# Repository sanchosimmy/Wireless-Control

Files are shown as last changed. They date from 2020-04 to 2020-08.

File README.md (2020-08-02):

/**
@mainpage Wireless home appliances control.

@author Akshay Pampatwar (Software)
@author Sancho Simmy Louis (Hardware Circuit Design)
@author Nijil George (Android App)
@author Sabitha Susan Joseph (PCB Design)

Appliances can be controlled via switches on a control board or a bluetooth mobile app. This project is developed for Tiva C tm4c123gh6pm uC. It can control following appliances:

(i)Fan

(ii)12 V Led strip

(iii)Plug1

(iv)Plug2

Hardware profiling of fan is done in the code thus even in case of low or over voltage of AC main line, Fan speed will remain constant for a given setting.
User specific setting of fan speed,led light brightness can be enabled from bluetooth app. 

In the starting, stored i.e. last values of Fan speed and Led Intensity will be used for control. 
Remainig inputs will be taken from hardware control panel i.e. switch board.
Thus in case of electricity failure, Fan speed and Led light brighteness will be restored but on/off state of appliances will depend on states of switches. User will have to resend commands via app for wireless control.

In case of multiple users, Latest command will be considered. 
Once commands are sent over a bluetooth, o/p states will remain unnchanged even if wireless link is lost. i.e. Switch status will be ignored, But changes in switch will be incorporarted. 
E.g. Currently switch for fan is on and fan is on. Now if turn off command sent wirelessly then fan will turned off. But if switch for fan is toggled from on to off and off to on then fan will be turned on (Even if wireless link exists thus latest command is considered for final state of o/p).

	Software is divided into 3 layers.

(i)Application layer

(ii)Middle layer

(iii)Hardware Abstraction layer

For time being, for simplicity many HAL functions are defined in a Middle layer files/module. e.g. Bluetooth,fan,led,plug etc.

	Working of code: 

(i) First code initializes all the o/p pins and i/p pins. Initiallly all the o/ps are off.

(ii)Status of fan speed and led light intensity is restored from eeprom.

(iii)Depending on status of switches appliances will be turned on.

(iv)If data is sent over a bluetooth then it will be decoded and stored in a global variable.

(v)Controller continuously checks changes in states of appliances (From Switchs or Wi Command) Depending on new commands will be enforced for turning on/off or change of speed of appliances.

(vi)New commands of fan speed and intensity will be saved in an eeprom.

	Read files from Documentation\html folder for more info on software / code.
*/

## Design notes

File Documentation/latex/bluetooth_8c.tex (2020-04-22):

\hypertarget{bluetooth_8c}{}\doxysection{C\+:/\+Users/\+Akshay/workspace\+\_\+v6\+\_\+0/\+Wireless\+\_\+\+Control/bluetooth.c File Reference}
\label{bluetooth_8c}\index{C:/Users/Akshay/workspace\_v6\_0/Wireless\_Control/bluetooth.c@{C:/Users/Akshay/workspace\_v6\_0/Wireless\_Control/bluetooth.c}}

Driver for bluetooth module.  

{\ttfamily \#include \char`\"{}bluetooth.\+h\char`\"{}}\newline
{\ttfamily \#include \char`\"{}commonheader.\+h\char`\"{}}\newline
{\ttfamily \#include \char`\"{}driverlib/uart.\+h\char`\"{}}\newline
{\ttfamily \#include \char`\"{}globalvariable.\+h\char`\"{}}\newline
{\ttfamily \#include \char`\"{}pinmap.\+h\char`\"{}}\newline
Include dependency graph for bluetooth.\+c\+:\nopagebreak
\begin{figure}[H]
\begin{center}
\leavevmode
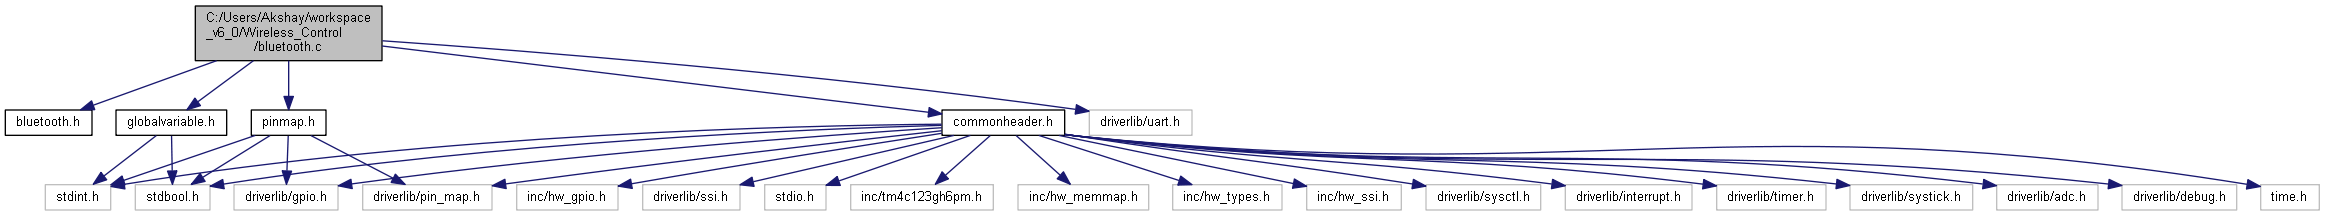
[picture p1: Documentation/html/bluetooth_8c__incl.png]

\end{center}
\end{figure}
\doxysubsection*{Functions}
\begin{DoxyCompactItemize}
\item 
void \mbox{\hyperlink{bluetooth_8c_ab92a40e570f765fd05c7c411f7a4d712}{Sys\+\_\+\+Uart\+Init}} (uint32\+\_\+t)
\item 
\mbox{\Hypertarget{bluetooth_8c_a2d4a537012aed004dd52d798fcc7498c}\label{bluetooth_8c_a2d4a537012aed004dd52d798fcc7498c}} 
void \mbox{\hyperlink{bluetooth_8c_a2d4a537012aed004dd52d798fcc7498c}{U\+A\+R\+T2\+Int\+Handler}} (void)
\begin{DoxyCompactList}\small\item\em Triggers when required depth of data rxed on Rx F\+I\+FO. \end{DoxyCompactList}\item 
\mbox{\Hypertarget{bluetooth_8c_a2ae308c73a93ebe0b32457e072f32a84}\label{bluetooth_8c_a2ae308c73a93ebe0b32457e072f32a84}} 
void \mbox{\hyperlink{bluetooth_8c_a2ae308c73a93ebe0b32457e072f32a84}{Get\+Uart\+Data}} (int32\+\_\+t Rx\+Temp)
\begin{DoxyCompactList}\small\item\em Gate fn for H\+AL to ML. I\+SR for rxed data for U\+A\+RT. \end{DoxyCompactList}\item 
\mbox{\Hypertarget{bluetooth_8c_a3931d6c801713463f51609ad20223707}\label{bluetooth_8c_a3931d6c801713463f51609ad20223707}} 
void \mbox{\hyperlink{bluetooth_8c_a3931d6c801713463f51609ad20223707}{Wip\+\_\+\+Init}} (void)
\begin{DoxyCompactList}\small\item\em Wireless input initialization for U\+A\+RT to serially communicate with bluetooth module. \end{DoxyCompactList}\end{DoxyCompactItemize}
\doxysubsection*{Variables}
\begin{DoxyCompactItemize}
\item 
\mbox{\Hypertarget{bluetooth_8c_a3948594ac93f0c5008fee3efcb07de77}\label{bluetooth_8c_a3948594ac93f0c5008fee3efcb07de77}} 
const uint32\+\_\+t {\bfseries B\+A\+U\+D\+R\+A\+TE} = 9600
\end{DoxyCompactItemize}

\doxysubsection{Detailed Description}
Driver for bluetooth module. 

\begin{DoxyAuthor}{Author}
Akshay Pampatwar 
\end{DoxyAuthor}
\begin{DoxyVersion}{Version}
0.\+0 
\end{DoxyVersion}
\begin{DoxyDate}{Date}
10th April 2020 
\end{DoxyDate}

\doxysubsection{Function Documentation}
\mbox{\Hypertarget{bluetooth_8c_ab92a40e570f765fd05c7c411f7a4d712}\label{bluetooth_8c_ab92a40e570f765fd05c7c411f7a4d712}} 
\index{bluetooth.c@{bluetooth.c}!Sys\_UartInit@{Sys\_UartInit}}
\index{Sys\_UartInit@{Sys\_UartInit}!bluetooth.c@{bluetooth.c}}
\doxysubsubsection{\texorpdfstring{Sys\_UartInit()}{Sys\_UartInit()}}
{\footnotesize\ttfamily void Sys\+\_\+\+Uart\+Init (\begin{DoxyParamCaption}\item[{uint32\+\_\+t}]{Baud\+Rate }\end{DoxyParamCaption})}

Initializez U\+A\+RT module 2 and setup I\+SR for rxed data 
\begin{DoxyParams}{Parameters}
{\em Baud\+\_\+\+Rate} & \\
\hline
\end{DoxyParams}

Definition at line 47 of file bluetooth.\+c.

Here is the caller graph for this function\+:\nopagebreak
\begin{figure}[H]
\begin{center}
\leavevmode

\end{center}
\end{figure}

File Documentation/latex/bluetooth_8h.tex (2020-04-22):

\hypertarget{bluetooth_8h}{}\doxysection{C\+:/\+Users/\+Akshay/workspace\+\_\+v6\+\_\+0/\+Wireless\+\_\+\+Control/bluetooth.h File Reference}
\label{bluetooth_8h}\index{C:/Users/Akshay/workspace\_v6\_0/Wireless\_Control/bluetooth.h@{C:/Users/Akshay/workspace\_v6\_0/Wireless\_Control/bluetooth.h}}

Function prototypes for bluetooth module.  

This graph shows which files directly or indirectly include this file\+:\nopagebreak
\begin{figure}[H]
\begin{center}
\leavevmode
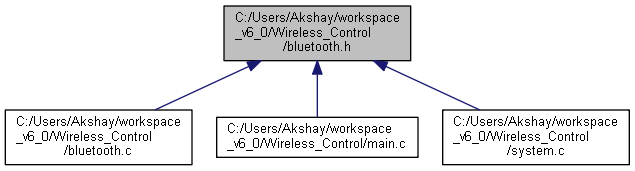
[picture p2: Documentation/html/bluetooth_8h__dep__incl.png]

\end{center}
\end{figure}
\doxysubsection*{Functions}
\begin{DoxyCompactItemize}
\item 
\mbox{\Hypertarget{bluetooth_8h_a3931d6c801713463f51609ad20223707}\label{bluetooth_8h_a3931d6c801713463f51609ad20223707}} 
void \mbox{\hyperlink{bluetooth_8h_a3931d6c801713463f51609ad20223707}{Wip\+\_\+\+Init}} (void)
\begin{DoxyCompactList}\small\item\em Wireless input initialization for U\+A\+RT to serially communicate with bluetooth module. \end{DoxyCompactList}\item 
\mbox{\Hypertarget{bluetooth_8h_ab61cf68b5b94e2ffc7ced2714f3d4968}\label{bluetooth_8h_ab61cf68b5b94e2ffc7ced2714f3d4968}} 
void \mbox{\hyperlink{bluetooth_8h_ab61cf68b5b94e2ffc7ced2714f3d4968}{Get\+Uart\+Data}} (int32\+\_\+t)
\begin{DoxyCompactList}\small\item\em Gate fn for H\+AL to ML. I\+SR for rxed data for U\+A\+RT. \end{DoxyCompactList}\end{DoxyCompactItemize}

\doxysubsection{Detailed Description}
Function prototypes for bluetooth module. 

Middle + Hardware abstraction layer. (i)Initializing serial port for communicating with bluetooth module. (ii)Updating data from user to corresponding global variable to control respective appliances. \begin{DoxyAuthor}{Author}
Akshay Pampatwar 
\end{DoxyAuthor}
\begin{DoxyVersion}{Version}
0.\+0 
\end{DoxyVersion}
\begin{DoxyDate}{Date}
10th April 2020 
\end{DoxyDate}

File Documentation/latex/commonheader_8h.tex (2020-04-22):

\hypertarget{commonheader_8h}{}\doxysection{C\+:/\+Users/\+Akshay/workspace\+\_\+v6\+\_\+0/\+Wireless\+\_\+\+Control/commonheader.h File Reference}
\label{commonheader_8h}\index{C:/Users/Akshay/workspace\_v6\_0/Wireless\_Control/commonheader.h@{C:/Users/Akshay/workspace\_v6\_0/Wireless\_Control/commonheader.h}}

Collection of header files.  

{\ttfamily \#include $<$stdio.\+h$>$}\newline
{\ttfamily \#include $<$stdint.\+h$>$}\newline
{\ttfamily \#include $<$stdbool.\+h$>$}\newline
{\ttfamily \#include \char`\"{}inc/tm4c123gh6pm.\+h\char`\"{}}\newline
{\ttfamily \#include \char`\"{}inc/hw\+\_\+memmap.\+h\char`\"{}}\newline
{\ttfamily \#include \char`\"{}inc/hw\+\_\+types.\+h\char`\"{}}\newline
{\ttfamily \#include \char`\"{}inc/hw\+\_\+ssi.\+h\char`\"{}}\newline
{\ttfamily \#include \char`\"{}driverlib/sysctl.\+h\char`\"{}}\newline
{\ttfamily \#include \char`\"{}driverlib/interrupt.\+h\char`\"{}}\newline
{\ttfamily \#include \char`\"{}driverlib/gpio.\+h\char`\"{}}\newline
{\ttfamily \#include \char`\"{}driverlib/timer.\+h\char`\"{}}\newline
{\ttfamily \#include \char`\"{}driverlib/systick.\+h\char`\"{}}\newline
{\ttfamily \#include \char`\"{}driverlib/adc.\+h\char`\"{}}\newline
{\ttfamily \#include \char`\"{}driverlib/debug.\+h\char`\"{}}\newline
{\ttfamily \#include $<$time.\+h$>$}\newline
{\ttfamily \#include $<$inc/hw\+\_\+gpio.\+h$>$}\newline
{\ttfamily \#include \char`\"{}driverlib/ssi.\+h\char`\"{}}\newline
{\ttfamily \#include \char`\"{}driverlib/pin\+\_\+map.\+h\char`\"{}}\newline
Include dependency graph for commonheader.\+h\+:\nopagebreak
\begin{figure}[H]
\begin{center}
\leavevmode

\end{center}
\end{figure}
This graph shows which files directly or indirectly include this file\+:\nopagebreak
\begin{figure}[H]
\begin{center}
\leavevmode

\end{center}
\end{figure}

\doxysubsection{Detailed Description}
Collection of header files. 

H\+AL\+: Hardware abstraction layer. Almost all header file of uC tm4c123gh6pm required to complete this project. \begin{DoxyNote}{Note}
Add it to source file of project. 
\end{DoxyNote}
\begin{DoxyAuthor}{Author}
Akshay Pampatwar 
\end{DoxyAuthor}
\begin{DoxyVersion}{Version}
0.\+0 
\end{DoxyVersion}
\begin{DoxyDate}{Date}
9th April 2020 
\end{DoxyDate}

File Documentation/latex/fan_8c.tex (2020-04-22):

\hypertarget{fan_8c}{}\doxysection{C\+:/\+Users/\+Akshay/workspace\+\_\+v6\+\_\+0/\+Wireless\+\_\+\+Control/fan.c File Reference}
\label{fan_8c}\index{C:/Users/Akshay/workspace\_v6\_0/Wireless\_Control/fan.c@{C:/Users/Akshay/workspace\_v6\_0/Wireless\_Control/fan.c}}

Driver for fan controlling.  

{\ttfamily \#include \char`\"{}fan.\+h\char`\"{}}\newline
{\ttfamily \#include \char`\"{}pinmap.\+h\char`\"{}}\newline
{\ttfamily \#include \char`\"{}commonheader.\+h\char`\"{}}\newline
{\ttfamily \#include \char`\"{}globalvariable.\+h\char`\"{}}\newline
{\ttfamily \#include \char`\"{}math.\+h\char`\"{}}\newline
Include dependency graph for fan.\+c\+:\nopagebreak
\begin{figure}[H]
\begin{center}
\leavevmode
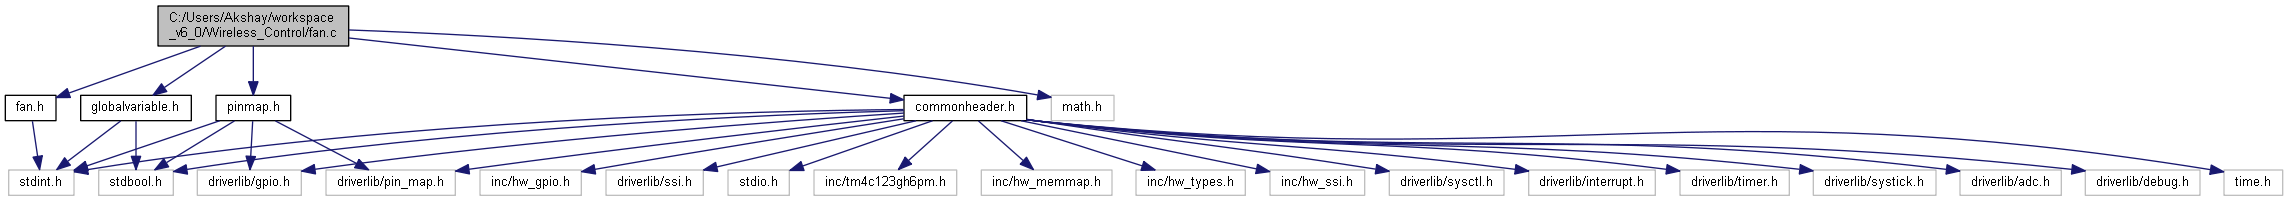
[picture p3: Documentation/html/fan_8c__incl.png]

\end{center}
\end{figure}
\doxysubsection*{Macros}
\begin{DoxyCompactItemize}
\item 
\mbox{\Hypertarget{fan_8c_a247e994e275a565320db53bed9462426}\label{fan_8c_a247e994e275a565320db53bed9462426}} 
\#define {\bfseries Scr\+Trigger\+Di}()~G\+P\+I\+O\+Int\+Disable(G\+P\+I\+O\+\_\+\+P\+O\+R\+T\+F\+\_\+\+B\+A\+SE, Z\+CD)
\item 
\mbox{\Hypertarget{fan_8c_a827d62ab62cd7dda6895929a0398709c}\label{fan_8c_a827d62ab62cd7dda6895929a0398709c}} 
\#define {\bfseries Scr\+Trigger\+En}()~G\+P\+I\+O\+Int\+Enable(G\+P\+I\+O\+\_\+\+P\+O\+R\+T\+F\+\_\+\+B\+A\+SE, Z\+CD)
\item 
\mbox{\Hypertarget{fan_8c_a7713aee3ee0d3c813de5fff0e284aa77}\label{fan_8c_a7713aee3ee0d3c813de5fff0e284aa77}} 
\#define {\bfseries S\+C\+R\+\_\+\+T\+R\+I\+G\+G\+E\+R\+\_\+\+PW}~2
\item 
\mbox{\Hypertarget{fan_8c_aa89bc308de7044aed78b7744f8bd9f2d}\label{fan_8c_aa89bc308de7044aed78b7744f8bd9f2d}} 
\#define {\bfseries Vrms\+\_\+\+Normal}~230
\end{DoxyCompactItemize}
\doxysubsection*{Functions}
\begin{DoxyCompactItemize}
\item 
\mbox{\Hypertarget{fan_8c_a2094bd7cf232d8d97c1af4a34dd2b723}\label{fan_8c_a2094bd7cf232d8d97c1af4a34dd2b723}} 
void \mbox{\hyperlink{fan_8c_a2094bd7cf232d8d97c1af4a34dd2b723}{Scr\+Pulse\+Tr}} (void)
\begin{DoxyCompactList}\small\item\em Generates 2 mS pulse to trigger fan S\+CR and Starts A\+DC sampling. \end{DoxyCompactList}\item 
\mbox{\Hypertarget{fan_8c_a048aee8573ecf21ed79e5c058fdf094d}\label{fan_8c_a048aee8573ecf21ed79e5c058fdf094d}} 
void \mbox{\hyperlink{fan_8c_a048aee8573ecf21ed79e5c058fdf094d}{Fan\+Full\+On}} (void)
\begin{DoxyCompactList}\small\item\em Turns on G\+P\+IO o/p pin of fan S\+CR for full AC vtg cycle. \end{DoxyCompactList}\item 
\mbox{\Hypertarget{fan_8c_a9aba447a5922b004e5283c120e1b5782}\label{fan_8c_a9aba447a5922b004e5283c120e1b5782}} 
void \mbox{\hyperlink{fan_8c_a9aba447a5922b004e5283c120e1b5782}{Fan\+\_\+\+Off\+\_\+\+Speed}} (void)
\begin{DoxyCompactList}\small\item\em Turns off fan if speed is 0. \end{DoxyCompactList}\item 
void \mbox{\hyperlink{fan_8c_ae2bf6e9d1d0cb94651d33913e9b038a0}{Fan\+Speed\+Ind\+Update}} (int8\+\_\+t)
\item 
\mbox{\Hypertarget{fan_8c_aa1fc5d33fce866bbc6603dbd846b2c33}\label{fan_8c_aa1fc5d33fce866bbc6603dbd846b2c33}} 
void \mbox{\hyperlink{fan_8c_aa1fc5d33fce866bbc6603dbd846b2c33}{Gpio\+Zero\+Cross\+Det\+Init}} (void)
\begin{DoxyCompactList}\small\item\em Initializes gpio pin as interrupt for rising edge trigger. For detecting zero crossing of AC vtg. \end{DoxyCompactList}\item 
void \mbox{\hyperlink{fan_8c_a97e91f37867e6a69ff463aac7c076b84}{Port\+F\+Int\+Handler}} (void)
\begin{DoxyCompactList}\small\item\em I\+SR for zero crossing.\+Update \& Starts timer1 (After that time S\+CR will be triggered) \end{DoxyCompactList}\item 
float \mbox{\hyperlink{fan_8c_a4c3218a32d123aa70edfaa91c893430a}{Vtg\+Swing\+Corr}} (float)
\item 
void \mbox{\hyperlink{fan_8c_a70802c5e162d9fbfeb1f6a27b293dc04}{Ac\+Vtg\+Rms}} (uint32\+\_\+t)
\item 
\mbox{\Hypertarget{fan_8c_a4bcca014a8288be81434b4be67f45b5a}\label{fan_8c_a4bcca014a8288be81434b4be67f45b5a}} 
void \mbox{\hyperlink{fan_8c_a4bcca014a8288be81434b4be67f45b5a}{Timer2\+B\+Init}} (void)
\begin{DoxyCompactList}\small\item\em Timer2B for pulse generation, S\+CR trigger pulse (2 mS) \end{DoxyCompactList}\item 
\mbox{\Hypertarget{fan_8c_a54477abd8e414c05f46a271e91282a14}\label{fan_8c_a54477abd8e414c05f46a271e91282a14}} 
void \mbox{\hyperlink{fan_8c_a54477abd8e414c05f46a271e91282a14}{Timer2\+B\+Int\+Handler}} (void)
\begin{DoxyCompactList}\small\item\em S\+CR pulse\+:I\+SR for Timer2B, Turns off S\+CR gpio pin. \end{DoxyCompactList}\item 
\mbox{\Hypertarget{fan_8c_a2806444250f7a6b55ea9b3ac603a52ae}\label{fan_8c_a2806444250f7a6b55ea9b3ac603a52ae}} 
void \mbox{\hyperlink{fan_8c_a2806444250f7a6b55ea9b3ac603a52ae}{Timer1\+Init}} (void)
\begin{DoxyCompactList}\small\item\em Timer1 for Scr trigger delay i.\+e. from 0 to 10 mS. \end{DoxyCompactList}\item 
\mbox{\Hypertarget{fan_8c_a65c79b40bb1ef0170ed09c5cd657f0f0}\label{fan_8c_a65c79b40bb1ef0170ed09c5cd657f0f0}} 
void \mbox{\hyperlink{fan_8c_a65c79b40bb1ef0170ed09c5cd657f0f0}{Timer1\+Int\+Handler}} (void)
\begin{DoxyCompactList}\small\item\em I\+SR for full Timer1. \end{DoxyCompactList}\item 
\mbox{\Hypertarget{fan_8c_a4aee6db188db234c1dcf4d17cc24eb03}\label{fan_8c_a4aee6db188db234c1dcf4d17cc24eb03}} 
void \mbox{\hyperlink{fan_8c_a4aee6db188db234c1dcf4d17cc24eb03}{A\+D\+C1\+\_\+\+Init}} (void)
\begin{DoxyCompactList}\small\item\em A\+DC module 1 initialize. \end{DoxyCompactList}\item 
\mbox{\Hypertarget{fan_8c_a34151cc19c669d08c8af5a052f124036}\label{fan_8c_a34151cc19c669d08c8af5a052f124036}} 
void \mbox{\hyperlink{fan_8c_a34151cc19c669d08c8af5a052f124036}{Adc1\+Int\+Handler}} (void)
\begin{DoxyCompactList}\small\item\em Takes sampled adc value and calls \mbox{\hyperlink{fan_8c_a70802c5e162d9fbfeb1f6a27b293dc04}{Ac\+Vtg\+Rms(uint32\+\_\+t)}} to save AC rms vtg. \end{DoxyCompactList}\item 
\mbox{\Hypertarget{fan_8c_abd21c776a93df2601476bddeb3300e88}\label{fan_8c_abd21c776a93df2601476bddeb3300e88}} 
void \mbox{\hyperlink{fan_8c_abd21c776a93df2601476bddeb3300e88}{Fan\+\_\+\+Init}} ()
\begin{DoxyCompactList}\small\item\em Initializes fan S\+CR driving port pin and A\+DC pin. \end{DoxyCompactList}\item 
\mbox{\Hypertarget{fan_8c_ad844825b3c02e9f2d77e61052acc3e4b}\label{fan_8c_ad844825b3c02e9f2d77e61052acc3e4b}} 
void \mbox{\hyperlink{fan_8c_ad844825b3c02e9f2d77e61052acc3e4b}{Fan\+\_\+\+On}} ()
\begin{DoxyCompactList}\small\item\em Turns on the fan, Fan speed rxed from \mbox{\hyperlink{fan_8h_a5459e7f51c969d8b256e9b5586317f92}{Fan\+\_\+\+Speed\+\_\+\+Update(int8\+\_\+t)}} function. \end{DoxyCompactList}\item 
\mbox{\Hypertarget{fan_8c_ab4c319da0d19780898b03a9b5ab658fe}\label{fan_8c_ab4c319da0d19780898b03a9b5ab658fe}} 
void \mbox{\hyperlink{fan_8c_ab4c319da0d19780898b03a9b5ab658fe}{Fan\+\_\+\+Off}} ()
\begin{DoxyCompactList}\small\item\em Turns off fan speed. \end{DoxyCompactList}\item 
void \mbox{\hyperlink{fan_8c_a45f472c9acb1834dd933b03ee530daf2}{Fan\+\_\+\+Speed\+\_\+\+Update}} (int8\+\_\+t Fan\+Speed)
\end{DoxyCompactItemize}
\doxysubsection*{Variables}
\begin{DoxyCompactItemize}
\item 
\mbox{\Hypertarget{fan_8c_a8d052979b138e8400ec8b8bb9601351b}\label{fan_8c_a8d052979b138e8400ec8b8bb9601351b}} 
float {\bfseries Scr\+Trg\+Delay} = 5.\+0
\end{DoxyCompactItemize}

\doxysubsection{Detailed Description}
Driver for fan controlling. 

\begin{DoxyAuthor}{Author}
Akshay Pampatwar 
\end{DoxyAuthor}
\begin{DoxyVersion}{Version}
0.\+0 
\end{DoxyVersion}
\begin{DoxyDate}{Date}
15th April 2020 
\end{DoxyDate}

\doxysubsection{Function Documentation}
\mbox{\Hypertarget{fan_8c_a70802c5e162d9fbfeb1f6a27b293dc04}\label{fan_8c_a70802c5e162d9fbfeb1f6a27b293dc04}} 
\index{fan.c@{fan.c}!AcVtgRms@{AcVtgRms}}
\index{AcVtgRms@{AcVtgRms}!fan.c@{fan.c}}
\doxysubsubsection{\texorpdfstring{AcVtgRms()}{AcVtgRms()}}
{\footnotesize\ttfamily void Ac\+Vtg\+Rms (\begin{DoxyParamCaption}\item[{uint32\+\_\+t}]{A\+D\+C\+Value }\end{DoxyParamCaption})}

Convert A\+DC sample into AC rms vtg and saves in Vrms variable. 
\begin{DoxyParams}{Parameters}
{\em A\+DC} & Reading\+: (uint32\+\_\+t) \\
\hline
\end{DoxyParams}

Definition at line 217 of file fan.\+c.

Here is the caller graph for this function\+:\nopagebreak
\begin{figure}[H]
\begin{center}
\leavevmode

\end{center}
\end{figure}
\mbox{\Hypertarget{fan_8c_a45f472c9acb1834dd933b03ee530daf2}\label{fan_8c_a45f472c9acb1834dd933b03ee530daf2}} 
\index{fan.c@{fan.c}!Fan\_Speed\_Update@{Fan\_Speed\_Update}}
\index{Fan\_Speed\_Update@{Fan\_Speed\_Update}!fan.c@{fan.c}}
\doxysubsubsection{\texorpdfstring{Fan\_Speed\_Update()}{Fan\_Speed\_Update()}}
{\footnotesize\ttfamily void Fan\+\_\+\+Speed\+\_\+\+Update (\begin{DoxyParamCaption}\item[{int8\+\_\+t}]{ }\end{DoxyParamCaption})}

Changes fan speed. 
\begin{DoxyParams}{Parameters}
{\em Fan\+Speed} & Fan speed from 0 to 5. lower limit should not be less than 0. \\
\hline
\end{DoxyParams}

Definition at line 126 of file fan.\+c.

Here is the call graph for this function\+:\nopagebreak
\begin{figure}[H]
\begin{center}
\leavevmode

\end{center}
\end{figure}
\mbox{\Hypertarget{fan_8c_ae2bf6e9d1d0cb94651d33913e9b038a0}\label{fan_8c_ae2bf6e9d1d0cb94651d33913e9b038a0}} 
\index{fan.c@{fan.c}!FanSpeedIndUpdate@{FanSpeedIndUpdate}}
\index{FanSpeedIndUpdate@{FanSpeedIndUpdate}!fan.c@{fan.c}}
\doxysubsubsection{\texorpdfstring{FanSpeedIndUpdate()}{FanSpeedIndUpdate()}}
{\footnotesize\ttfamily void Fan\+Speed\+Ind\+Update (\begin{DoxyParamCaption}\item[{int8\+\_\+t}]{Fan\+Speed }\end{DoxyParamCaption})}

Turns on indicator L\+ED depending on fan speed 
\begin{DoxyParams}{Parameters}
{\em Fan\+Speed} & 0 to 5 \\
\hline
\end{DoxyParams}

Definition at line 161 of file fan.\+c.

\mbox{\Hypertarget{fan_8c_a97e91f37867e6a69ff463aac7c076b84}\label{fan_8c_a97e91f37867e6a69ff463aac7c076b84}} 
\index{fan.c@{fan.c}!PortFIntHandler@{PortFIntHandler}}
\index{PortFIntHandler@{PortFIntHandler}!fan.c@{fan.c}}
\doxysubsubsection{\texorpdfstring{PortFIntHandler()}{PortFIntHandler()}}
{\footnotesize\ttfamily void Port\+F\+Int\+Handler (\begin{DoxyParamCaption}\item[{void}]{ }\end{DoxyParamCaption})}

I\+SR for zero crossing.\+Update \& Starts timer1 (After that time S\+CR will be triggered) 

Zero crossing detection I\+SR\+: Triggers Timer1 for S\+CR trigger delay. 

Definition at line 307 of file fan.\+c.

\mbox{\Hypertarget{fan_8c_a4c3218a32d123aa70edfaa91c893430a}\label{fan_8c_a4c3218a32d123aa70edfaa91c893430a}} 
\index{fan.c@{fan.c}!VtgSwingCorr@{VtgSwingCorr}}
\index{VtgSwingCorr@{VtgSwingCorr}!fan.c@{fan.c}}
\doxysubsubsection{\texorpdfstring{VtgSwingCorr()}{VtgSwingCorr()}}
{\footnotesize\ttfamily float Vtg\+Swing\+Corr (\begin{DoxyParamCaption}\item[{float}]{trigger\+Angle }\end{DoxyParamCaption})}

Correction of S\+CR trigger time depending on Line freq and AC rms voltage. 
\begin{DoxyParams}{Parameters}
{\em Trigger\+\_\+angle} & (0 to 180) \\
\hline
\end{DoxyParams}
\begin{DoxyReturn}{Returns}
Scr Trigger delay\+: (mS) Corresponding to i/p trigger angle \& AC vgt correction. 
\end{DoxyReturn}

Definition at line 152 of file fan.\+c.

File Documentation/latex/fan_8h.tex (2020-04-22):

\hypertarget{fan_8h}{}\doxysection{C\+:/\+Users/\+Akshay/workspace\+\_\+v6\+\_\+0/\+Wireless\+\_\+\+Control/fan.h File Reference}
\label{fan_8h}\index{C:/Users/Akshay/workspace\_v6\_0/Wireless\_Control/fan.h@{C:/Users/Akshay/workspace\_v6\_0/Wireless\_Control/fan.h}}

Functionn prototypes for fan controlling.  

{\ttfamily \#include $<$stdint.\+h$>$}\newline
Include dependency graph for fan.\+h\+:\nopagebreak
\begin{figure}[H]
\begin{center}
\leavevmode
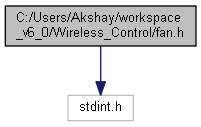
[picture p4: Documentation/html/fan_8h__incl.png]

\end{center}
\end{figure}
This graph shows which files directly or indirectly include this file\+:\nopagebreak
\begin{figure}[H]
\begin{center}
\leavevmode
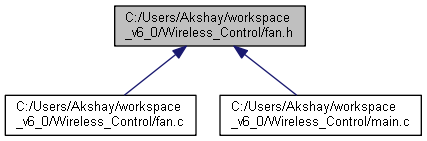
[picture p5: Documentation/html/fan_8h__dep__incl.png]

\end{center}
\end{figure}
\doxysubsection*{Functions}
\begin{DoxyCompactItemize}
\item 
\mbox{\Hypertarget{fan_8h_a3aa310cfa76c5690786c4e386ee229d9}\label{fan_8h_a3aa310cfa76c5690786c4e386ee229d9}} 
void \mbox{\hyperlink{fan_8h_a3aa310cfa76c5690786c4e386ee229d9}{Fan\+\_\+\+Init}} (void)
\begin{DoxyCompactList}\small\item\em Initializes fan S\+CR driving port pin and A\+DC pin. \end{DoxyCompactList}\item 
\mbox{\Hypertarget{fan_8h_a4867ab95fc15e966bf62fd86e3f6b51c}\label{fan_8h_a4867ab95fc15e966bf62fd86e3f6b51c}} 
void \mbox{\hyperlink{fan_8h_a4867ab95fc15e966bf62fd86e3f6b51c}{Fan\+\_\+\+On}} (void)
\begin{DoxyCompactList}\small\item\em Turns on the fan, Fan speed rxed from \mbox{\hyperlink{fan_8h_a5459e7f51c969d8b256e9b5586317f92}{Fan\+\_\+\+Speed\+\_\+\+Update(int8\+\_\+t)}} function. \end{DoxyCompactList}\item 
\mbox{\Hypertarget{fan_8h_a07cd289f0eeb148213b422ce96e71f5a}\label{fan_8h_a07cd289f0eeb148213b422ce96e71f5a}} 
void \mbox{\hyperlink{fan_8h_a07cd289f0eeb148213b422ce96e71f5a}{Fan\+\_\+\+Off}} (void)
\begin{DoxyCompactList}\small\item\em Turns off fan speed. \end{DoxyCompactList}\item 
void \mbox{\hyperlink{fan_8h_a5459e7f51c969d8b256e9b5586317f92}{Fan\+\_\+\+Speed\+\_\+\+Update}} (int8\+\_\+t)
\end{DoxyCompactItemize}

\doxysubsection{Detailed Description}
Functionn prototypes for fan controlling. 

HA + Middle layer. In case of reset of board, Saved last fan speed will be set. Requires gloabalvariable.\+h access for M\+A\+X\+F\+A\+N\+S\+P\+E\+ED value. (i)Initializes relevant port pin as an o/p, A\+DC pin and two timers. (ii)Calculates AC voltage from A\+DC reading. (iii)Depending on AC rms vtg and user provided speed, Calculates trigger delay after zero crossing of AC vtg for scr driving. (iv)In case of voltage fluctuation speed of fan will remain same.

\begin{DoxyAuthor}{Author}
Akshay Pampatwar 
\end{DoxyAuthor}
\begin{DoxyVersion}{Version}
0.\+0 
\end{DoxyVersion}
\begin{DoxyDate}{Date}
15th April 2020 
\end{DoxyDate}

\doxysubsection{Function Documentation}
\mbox{\Hypertarget{fan_8h_a5459e7f51c969d8b256e9b5586317f92}\label{fan_8h_a5459e7f51c969d8b256e9b5586317f92}} 
\index{fan.h@{fan.h}!Fan\_Speed\_Update@{Fan\_Speed\_Update}}
\index{Fan\_Speed\_Update@{Fan\_Speed\_Update}!fan.h@{fan.h}}
\doxysubsubsection{\texorpdfstring{Fan\_Speed\_Update()}{Fan\_Speed\_Update()}}
{\footnotesize\ttfamily void Fan\+\_\+\+Speed\+\_\+\+Update (\begin{DoxyParamCaption}\item[{int8\+\_\+t}]{ }\end{DoxyParamCaption})}

Changes fan speed. 
\begin{DoxyParams}{Parameters}
{\em Fan\+Speed} & Fan speed from 0 to 5. lower limit should not be less than 0. \\
\hline
\end{DoxyParams}

Definition at line 126 of file fan.\+c.

Here is the call graph for this function\+:\nopagebreak
\begin{figure}[H]
\begin{center}
\leavevmode

\end{center}
\end{figure}

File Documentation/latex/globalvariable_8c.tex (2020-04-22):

\hypertarget{globalvariable_8c}{}\doxysection{C\+:/\+Users/\+Akshay/workspace\+\_\+v6\+\_\+0/\+Wireless\+\_\+\+Control/globalvariable.c File Reference}
\label{globalvariable_8c}\index{C:/Users/Akshay/workspace\_v6\_0/Wireless\_Control/globalvariable.c@{C:/Users/Akshay/workspace\_v6\_0/Wireless\_Control/globalvariable.c}}

Gloabal variables defination and initialization.  

{\ttfamily \#include \char`\"{}globalvariable.\+h\char`\"{}}\newline
Include dependency graph for globalvariable.\+c\+:\nopagebreak
\begin{figure}[H]
\begin{center}
\leavevmode
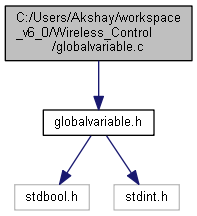
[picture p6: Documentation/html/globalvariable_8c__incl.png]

\end{center}
\end{figure}
\doxysubsection*{Variables}
\begin{DoxyCompactItemize}
\item 
\mbox{\Hypertarget{globalvariable_8c_a3672e90e5b0a8d5192c296892b24db0b}\label{globalvariable_8c_a3672e90e5b0a8d5192c296892b24db0b}} 
const int {\bfseries M\+A\+X\+\_\+\+F\+A\+N\+\_\+\+S\+P\+E\+ED} =5
\item 
\mbox{\Hypertarget{globalvariable_8c_a683a26800849e22e37dc3307f0bb2308}\label{globalvariable_8c_a683a26800849e22e37dc3307f0bb2308}} 
const int {\bfseries M\+I\+N\+\_\+\+F\+A\+N\+\_\+\+S\+P\+E\+ED} = 0
\item 
\mbox{\Hypertarget{globalvariable_8c_a4c3de1db1d0118753119c60e55481b19}\label{globalvariable_8c_a4c3de1db1d0118753119c60e55481b19}} 
const int {\bfseries M\+A\+X\+\_\+\+L\+E\+D\+\_\+\+B\+R\+I\+G\+H\+T\+N\+E\+SS} = 5
\item 
\mbox{\Hypertarget{globalvariable_8c_a611fba266ebd7798edc9829dc048fd4a}\label{globalvariable_8c_a611fba266ebd7798edc9829dc048fd4a}} 
const int {\bfseries M\+I\+N\+\_\+\+L\+E\+D\+\_\+\+B\+R\+I\+G\+H\+T\+N\+E\+SS} =0
\item 
\mbox{\Hypertarget{globalvariable_8c_adf972fab2e7892d4f81c198f2dc4285c}\label{globalvariable_8c_adf972fab2e7892d4f81c198f2dc4285c}} 
bool {\bfseries Fan\+\_\+\+Cmd} = 0
\item 
\mbox{\Hypertarget{globalvariable_8c_a955d00d52f811c7930ccc881323de958}\label{globalvariable_8c_a955d00d52f811c7930ccc881323de958}} 
int8\+\_\+t {\bfseries Fan\+\_\+\+Speed} = 0
\item 
\mbox{\Hypertarget{globalvariable_8c_af581f0be5d2aa677184ec459a8a3c7bf}\label{globalvariable_8c_af581f0be5d2aa677184ec459a8a3c7bf}} 
bool {\bfseries Led\+\_\+\+Cmd} = 0
\item 
\mbox{\Hypertarget{globalvariable_8c_aa817b5f2c7881a643c2170e419d92552}\label{globalvariable_8c_aa817b5f2c7881a643c2170e419d92552}} 
int8\+\_\+t {\bfseries Led\+\_\+\+Brightness} = 0
\item 
\mbox{\Hypertarget{globalvariable_8c_a6bec4ff681a180ff64326c6cb4187ef3}\label{globalvariable_8c_a6bec4ff681a180ff64326c6cb4187ef3}} 
bool {\bfseries Plug1\+\_\+\+Cmd} = 0
\item 
\mbox{\Hypertarget{globalvariable_8c_a31e3f498b02057d67d85c4ec56fc33f1}\label{globalvariable_8c_a31e3f498b02057d67d85c4ec56fc33f1}} 
bool {\bfseries Plug2\+\_\+\+Cmd} = 0
\item 
\mbox{\Hypertarget{globalvariable_8c_a59a42d9cfa5ec04c350a7b5c4ff5abb7}\label{globalvariable_8c_a59a42d9cfa5ec04c350a7b5c4ff5abb7}} 
bool {\bfseries Fan\+\_\+\+N\+Cmd} = 0
\item 
\mbox{\Hypertarget{globalvariable_8c_abd68eb702e45aa0ff1222aa2b889fe82}\label{globalvariable_8c_abd68eb702e45aa0ff1222aa2b889fe82}} 
bool {\bfseries Fan\+\_\+\+Nspeed} = 0
\item 
\mbox{\Hypertarget{globalvariable_8c_a5219f06eb1dc8b52a9131cf643b80156}\label{globalvariable_8c_a5219f06eb1dc8b52a9131cf643b80156}} 
bool {\bfseries Led\+\_\+\+N\+Cmd} = 0
\item 
\mbox{\Hypertarget{globalvariable_8c_a24c5e2cc3dae36d9bc7f6cfd7e150f95}\label{globalvariable_8c_a24c5e2cc3dae36d9bc7f6cfd7e150f95}} 
bool {\bfseries Led\+\_\+\+N\+Brightness} = 0
\item 
\mbox{\Hypertarget{globalvariable_8c_a624160b021593086721f383bc76e8a4c}\label{globalvariable_8c_a624160b021593086721f383bc76e8a4c}} 
bool {\bfseries Plug1\+\_\+\+N\+Cmd} = 0
\item 
\mbox{\Hypertarget{globalvariable_8c_a166340e052a5d3809e697e34c643ce07}\label{globalvariable_8c_a166340e052a5d3809e697e34c643ce07}} 
bool {\bfseries Plug2\+\_\+\+N\+Cmd} = 0
\end{DoxyCompactItemize}

\doxysubsection{Detailed Description}
Gloabal variables defination and initialization. 

\begin{DoxyAuthor}{Author}
Akshay Pampatwar 
\end{DoxyAuthor}
\begin{DoxyVersion}{Version}
0.\+0 
\end{DoxyVersion}
\begin{DoxyDate}{Date}
14th April 2020 
\end{DoxyDate}

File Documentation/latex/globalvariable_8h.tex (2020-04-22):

\hypertarget{globalvariable_8h}{}\doxysection{C\+:/\+Users/\+Akshay/workspace\+\_\+v6\+\_\+0/\+Wireless\+\_\+\+Control/globalvariable.h File Reference}
\label{globalvariable_8h}\index{C:/Users/Akshay/workspace\_v6\_0/Wireless\_Control/globalvariable.h@{C:/Users/Akshay/workspace\_v6\_0/Wireless\_Control/globalvariable.h}}

Global variables for saving status of all inputs.  

{\ttfamily \#include $<$stdbool.\+h$>$}\newline
{\ttfamily \#include $<$stdint.\+h$>$}\newline
Include dependency graph for globalvariable.\+h\+:\nopagebreak
\begin{figure}[H]
\begin{center}
\leavevmode
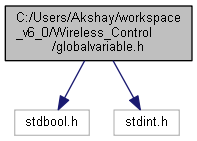
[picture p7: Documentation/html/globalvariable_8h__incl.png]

\end{center}
\end{figure}
This graph shows which files directly or indirectly include this file\+:\nopagebreak
\begin{figure}[H]
\begin{center}
\leavevmode

\end{center}
\end{figure}
\doxysubsection*{Variables}
\begin{DoxyCompactItemize}
\item 
\mbox{\Hypertarget{globalvariable_8h_a3672e90e5b0a8d5192c296892b24db0b}\label{globalvariable_8h_a3672e90e5b0a8d5192c296892b24db0b}} 
const int {\bfseries M\+A\+X\+\_\+\+F\+A\+N\+\_\+\+S\+P\+E\+ED}
\item 
\mbox{\Hypertarget{globalvariable_8h_a683a26800849e22e37dc3307f0bb2308}\label{globalvariable_8h_a683a26800849e22e37dc3307f0bb2308}} 
const int {\bfseries M\+I\+N\+\_\+\+F\+A\+N\+\_\+\+S\+P\+E\+ED}
\item 
\mbox{\Hypertarget{globalvariable_8h_a4c3de1db1d0118753119c60e55481b19}\label{globalvariable_8h_a4c3de1db1d0118753119c60e55481b19}} 
const int {\bfseries M\+A\+X\+\_\+\+L\+E\+D\+\_\+\+B\+R\+I\+G\+H\+T\+N\+E\+SS}
\item 
\mbox{\Hypertarget{globalvariable_8h_a611fba266ebd7798edc9829dc048fd4a}\label{globalvariable_8h_a611fba266ebd7798edc9829dc048fd4a}} 
const int {\bfseries M\+I\+N\+\_\+\+L\+E\+D\+\_\+\+B\+R\+I\+G\+H\+T\+N\+E\+SS}
\item 
\mbox{\Hypertarget{globalvariable_8h_adf972fab2e7892d4f81c198f2dc4285c}\label{globalvariable_8h_adf972fab2e7892d4f81c198f2dc4285c}} 
bool {\bfseries Fan\+\_\+\+Cmd}
\item 
\mbox{\Hypertarget{globalvariable_8h_a955d00d52f811c7930ccc881323de958}\label{globalvariable_8h_a955d00d52f811c7930ccc881323de958}} 
int8\+\_\+t {\bfseries Fan\+\_\+\+Speed}
\item 
\mbox{\Hypertarget{globalvariable_8h_af581f0be5d2aa677184ec459a8a3c7bf}\label{globalvariable_8h_af581f0be5d2aa677184ec459a8a3c7bf}} 
bool {\bfseries Led\+\_\+\+Cmd}
\item 
\mbox{\Hypertarget{globalvariable_8h_aa817b5f2c7881a643c2170e419d92552}\label{globalvariable_8h_aa817b5f2c7881a643c2170e419d92552}} 
int8\+\_\+t {\bfseries Led\+\_\+\+Brightness}
\item 
\mbox{\Hypertarget{globalvariable_8h_a6bec4ff681a180ff64326c6cb4187ef3}\label{globalvariable_8h_a6bec4ff681a180ff64326c6cb4187ef3}} 
bool {\bfseries Plug1\+\_\+\+Cmd}
\item 
\mbox{\Hypertarget{globalvariable_8h_a31e3f498b02057d67d85c4ec56fc33f1}\label{globalvariable_8h_a31e3f498b02057d67d85c4ec56fc33f1}} 
bool {\bfseries Plug2\+\_\+\+Cmd}
\item 
\mbox{\Hypertarget{globalvariable_8h_a59a42d9cfa5ec04c350a7b5c4ff5abb7}\label{globalvariable_8h_a59a42d9cfa5ec04c350a7b5c4ff5abb7}} 
bool {\bfseries Fan\+\_\+\+N\+Cmd}
\item 
\mbox{\Hypertarget{globalvariable_8h_abd68eb702e45aa0ff1222aa2b889fe82}\label{globalvariable_8h_abd68eb702e45aa0ff1222aa2b889fe82}} 
bool {\bfseries Fan\+\_\+\+Nspeed}
\item 
\mbox{\Hypertarget{globalvariable_8h_a5219f06eb1dc8b52a9131cf643b80156}\label{globalvariable_8h_a5219f06eb1dc8b52a9131cf643b80156}} 
bool {\bfseries Led\+\_\+\+N\+Cmd}
\item 
\mbox{\Hypertarget{globalvariable_8h_a24c5e2cc3dae36d9bc7f6cfd7e150f95}\label{globalvariable_8h_a24c5e2cc3dae36d9bc7f6cfd7e150f95}} 
bool {\bfseries Led\+\_\+\+N\+Brightness}
\item 
\mbox{\Hypertarget{globalvariable_8h_a624160b021593086721f383bc76e8a4c}\label{globalvariable_8h_a624160b021593086721f383bc76e8a4c}} 
bool {\bfseries Plug1\+\_\+\+N\+Cmd}
\item 
\mbox{\Hypertarget{globalvariable_8h_a166340e052a5d3809e697e34c643ce07}\label{globalvariable_8h_a166340e052a5d3809e697e34c643ce07}} 
bool {\bfseries Plug2\+\_\+\+N\+Cmd}
\end{DoxyCompactItemize}

\doxysubsection{Detailed Description}
Global variables for saving status of all inputs. 

Application layer and middle layer. Includes declaration of inputs of all appliances. Used for transferring data from \mbox{\hyperlink{input_8h}{input.\+h}} and \mbox{\hyperlink{bluetooth_8h}{bluetooth.\+h}} to controller. Also required for \mbox{\hyperlink{fan_8h}{fan.\+h}} and \mbox{\hyperlink{led_8h}{led.\+h}} since it uses M\+A\+X\+\_\+\+L\+E\+D\+\_\+\+B\+R\+I\+G\+H\+T\+N\+E\+SS \& M\+A\+X\+\_\+\+F\+A\+N\+\_\+\+S\+P\+E\+ED. \begin{DoxyAuthor}{Author}
Akshay Pampatwar 
\end{DoxyAuthor}
\begin{DoxyVersion}{Version}
0.\+0 
\end{DoxyVersion}
\begin{DoxyDate}{Date}
12th April 2020 
\end{DoxyDate}

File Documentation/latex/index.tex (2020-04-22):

\begin{DoxyAuthor}{Author}
Akshay Pampatwar 

Sancho Simmy Louis 

Nijil George 

Sabitha Susan Joseph
\end{DoxyAuthor}
Appliances can be controlled via switches on a control board or a bluetooth mobile app. This project is developed for Tiva C tm4c123gh6pm uC. It can control following appliances\+:

(i)Fan

(ii)12 V Led strip

(iii)Plug1

(iv)Plug2

Hardware profiling of fan is done in the code thus even in case of low or over voltage of AC main line, Fan speed will remain constant for a given setting. User specific setting of fan speed,led light brightness can be enabled from bluetooth app.

In the starting, stored i.\+e. last values of Fan speed and Led Intensity will be used for control. Remainig inputs will be taken from hardware control panel i.\+e. switch board. Thus in case of electricity failure, Fan speed and Led light brighteness will be restored but on/off state of appliances will depend on states of switches. User will have to resend commands via app for wireless control.

In case of multiple users, Latest command will be considered. Once commands are sent over a bluetooth, o/p states will remain unnchanged even if wireless link is lost. i.\+e. Switch status will be ignored, But changes in switch will be incorporarted. E.\+g. Currently switch for fan is on and fan is on. Now if turn off command sent wirelessly then fan will turned off. But if switch for fan is toggled from on to off and off to on then fan will be turned on (Even if wireless link exists thus latest command is considered for final state of o/p). \begin{DoxyVerb}Software is divided into 3 layers.
\end{DoxyVerb}

(i)Application layer

(ii)Middle layer

(iii)Hardware Abstraction layer

For time being, for simplicity many H\+AL functions are defined in a Middle layer files/module. e.\+g. Bluetooth,fan,led,plug etc. \begin{DoxyVerb}Working of code: 
\end{DoxyVerb}

(i) First code initializes all the o/p pins and i/p pins. Initiallly all the o/ps are off.

(ii)Status of fan speed and led light intensity is restored from eeprom.

(iii)Depending on status of switches appliances will be turned on.

(iv)If data is sent over a bluetooth then it will be decoded and stored in a global variable.

(v)Controller continuously checks changes in states of appliances (From Switchs or Wi Command) Depending on new commands will be enforced for turning on/off or change of speed of appliances.

(vi)New commands of fan speed and intensity will be saved in an eeprom.

$\ast$/

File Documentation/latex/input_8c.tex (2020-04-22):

\hypertarget{input_8c}{}\doxysection{C\+:/\+Users/\+Akshay/workspace\+\_\+v6\+\_\+0/\+Wireless\+\_\+\+Control/input.c File Reference}
\label{input_8c}\index{C:/Users/Akshay/workspace\_v6\_0/Wireless\_Control/input.c@{C:/Users/Akshay/workspace\_v6\_0/Wireless\_Control/input.c}}

Driver for scanning switches.  

{\ttfamily \#include \char`\"{}input.\+h\char`\"{}}\newline
{\ttfamily \#include \char`\"{}commonheader.\+h\char`\"{}}\newline
{\ttfamily \#include \char`\"{}system.\+h\char`\"{}}\newline
{\ttfamily \#include \char`\"{}globalvariable.\+h\char`\"{}}\newline
{\ttfamily \#include \char`\"{}pinmap.\+h\char`\"{}}\newline
Include dependency graph for input.\+c\+:\nopagebreak
\begin{figure}[H]
\begin{center}
\leavevmode
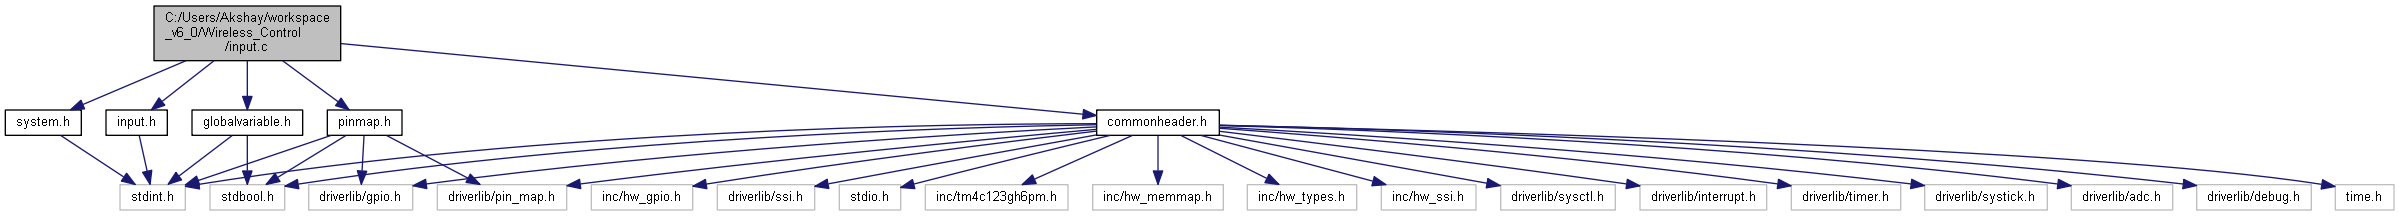
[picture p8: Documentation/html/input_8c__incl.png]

\end{center}
\end{figure}
\doxysubsection*{Macros}
\begin{DoxyCompactItemize}
\item 
\mbox{\Hypertarget{input_8c_a00aef9e8dd001a49f8717031d84b2c6c}\label{input_8c_a00aef9e8dd001a49f8717031d84b2c6c}} 
\#define {\bfseries D\+E\+B\+O\+U\+N\+C\+E\+\_\+\+T\+I\+ME}~20
\end{DoxyCompactItemize}
\doxysubsection*{Functions}
\begin{DoxyCompactItemize}
\item 
\mbox{\Hypertarget{input_8c_a5b83d6f82fe6a690e947a091d9a7f0a4}\label{input_8c_a5b83d6f82fe6a690e947a091d9a7f0a4}} 
void {\bfseries Fan\+Speed\+Update} (void)
\item 
\mbox{\Hypertarget{input_8c_a1f5fdd46fbe2c20cb8971dae6556b796}\label{input_8c_a1f5fdd46fbe2c20cb8971dae6556b796}} 
void {\bfseries Led\+Brightness\+Update} (void)
\item 
\mbox{\Hypertarget{input_8c_ab6d895e09540216fe11d738e09898794}\label{input_8c_ab6d895e09540216fe11d738e09898794}} 
void \mbox{\hyperlink{input_8c_ab6d895e09540216fe11d738e09898794}{Input\+\_\+\+Init}} (void)
\begin{DoxyCompactList}\small\item\em Middle layer fn. Initializes G\+P\+IO as an input for all the switches. \end{DoxyCompactList}\item 
void \mbox{\hyperlink{input_8c_aa824b14a8fe97b88f0ba0ed98a3e1791}{Gpip}} (uint32\+\_\+t current\+IP)
\end{DoxyCompactItemize}

\doxysubsection{Detailed Description}
Driver for scanning switches. 

\begin{DoxyAuthor}{Author}
Akshay Pampatwar 
\end{DoxyAuthor}
\begin{DoxyVersion}{Version}
0.\+0 
\end{DoxyVersion}
\begin{DoxyDate}{Date}
11th April 2020 
\end{DoxyDate}

\doxysubsection{Function Documentation}
\mbox{\Hypertarget{input_8c_aa824b14a8fe97b88f0ba0ed98a3e1791}\label{input_8c_aa824b14a8fe97b88f0ba0ed98a3e1791}} 
\index{input.c@{input.c}!Gpip@{Gpip}}
\index{Gpip@{Gpip}!input.c@{input.c}}
\doxysubsubsection{\texorpdfstring{Gpip()}{Gpip()}}
{\footnotesize\ttfamily void Gpip (\begin{DoxyParamCaption}\item[{uint32\+\_\+t}]{current\+IP }\end{DoxyParamCaption})}

I\+SR\+: Called after every debounce period (20mS). Gate called from H\+AL to Middle layer

(i)Take care of bounce back effect of switches. (ii)Updates Changed in a output to a global variable related to home appliances. 
\begin{DoxyParams}{Parameters}
{\em current\+IP} & \+: 32 bit which is an encoded status of all switches interface with Port A and Port D. 2nd last byte = Port A \& L\+S\+Byte = Port D \\
\hline
\end{DoxyParams}

Definition at line 33 of file input.\+c.

Here is the caller graph for this function\+:\nopagebreak
\begin{figure}[H]
\begin{center}
\leavevmode

\end{center}
\end{figure}

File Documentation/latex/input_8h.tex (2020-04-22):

\hypertarget{input_8h}{}\doxysection{C\+:/\+Users/\+Akshay/workspace\+\_\+v6\+\_\+0/\+Wireless\+\_\+\+Control/input.h File Reference}
\label{input_8h}\index{C:/Users/Akshay/workspace\_v6\_0/Wireless\_Control/input.h@{C:/Users/Akshay/workspace\_v6\_0/Wireless\_Control/input.h}}

Function prototype for scanning switches and updating final status of input.  

{\ttfamily \#include $<$stdint.\+h$>$}\newline
Include dependency graph for input.\+h\+:\nopagebreak
\begin{figure}[H]
\begin{center}
\leavevmode
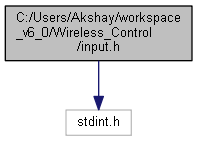
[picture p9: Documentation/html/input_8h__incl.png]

\end{center}
\end{figure}
This graph shows which files directly or indirectly include this file\+:\nopagebreak
\begin{figure}[H]
\begin{center}
\leavevmode
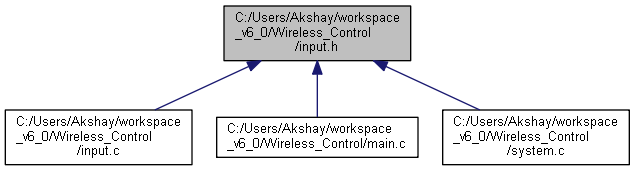
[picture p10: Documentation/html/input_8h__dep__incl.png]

\end{center}
\end{figure}
\doxysubsection*{Functions}
\begin{DoxyCompactItemize}
\item 
\mbox{\Hypertarget{input_8h_ab6d895e09540216fe11d738e09898794}\label{input_8h_ab6d895e09540216fe11d738e09898794}} 
void \mbox{\hyperlink{input_8h_ab6d895e09540216fe11d738e09898794}{Input\+\_\+\+Init}} (void)
\begin{DoxyCompactList}\small\item\em Middle layer fn. Initializes G\+P\+IO as an input for all the switches. \end{DoxyCompactList}\item 
void \mbox{\hyperlink{input_8h_aa824b14a8fe97b88f0ba0ed98a3e1791}{Gpip}} (uint32\+\_\+t current\+IP)
\end{DoxyCompactItemize}

\doxysubsection{Detailed Description}
Function prototype for scanning switches and updating final status of input. 

Middle layer. Read switches for input and updates status in global variables \begin{DoxyAuthor}{Author}
Akshay Pampatwar 
\end{DoxyAuthor}
\begin{DoxyVersion}{Version}
0.\+0 
\end{DoxyVersion}
\begin{DoxyDate}{Date}
11th April 2020 
\end{DoxyDate}

\doxysubsection{Function Documentation}
\mbox{\Hypertarget{input_8h_aa824b14a8fe97b88f0ba0ed98a3e1791}\label{input_8h_aa824b14a8fe97b88f0ba0ed98a3e1791}} 
\index{input.h@{input.h}!Gpip@{Gpip}}
\index{Gpip@{Gpip}!input.h@{input.h}}
\doxysubsubsection{\texorpdfstring{Gpip()}{Gpip()}}
{\footnotesize\ttfamily void Gpip (\begin{DoxyParamCaption}\item[{uint32\+\_\+t}]{current\+IP }\end{DoxyParamCaption})}

I\+SR\+: Called after every debounce period (20mS). Gate called from H\+AL to Middle layer

(i)Take care of bounce back effect of switches. (ii)Updates Changed in a output to a global variable related to home appliances. 
\begin{DoxyParams}{Parameters}
{\em current\+IP} & \+: 32 bit which is an encoded status of all switches interface with Port A and Port D. 2nd last byte = Port A \& L\+S\+Byte = Port D \\
\hline
\end{DoxyParams}

Definition at line 33 of file input.\+c.

Here is the caller graph for this function\+:\nopagebreak
\begin{figure}[H]
\begin{center}
\leavevmode

\end{center}
\end{figure}

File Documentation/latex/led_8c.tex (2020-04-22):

\hypertarget{led_8c}{}\doxysection{C\+:/\+Users/\+Akshay/workspace\+\_\+v6\+\_\+0/\+Wireless\+\_\+\+Control/led.c File Reference}
\label{led_8c}\index{C:/Users/Akshay/workspace\_v6\_0/Wireless\_Control/led.c@{C:/Users/Akshay/workspace\_v6\_0/Wireless\_Control/led.c}}

Driver for L\+ED strip control.  

{\ttfamily \#include \char`\"{}led.\+h\char`\"{}}\newline
{\ttfamily \#include \char`\"{}commonheader.\+h\char`\"{}}\newline
{\ttfamily \#include \char`\"{}pinmap.\+h\char`\"{}}\newline
{\ttfamily \#include \char`\"{}globalvariable.\+h\char`\"{}}\newline
Include dependency graph for led.\+c\+:\nopagebreak
\begin{figure}[H]
\begin{center}
\leavevmode
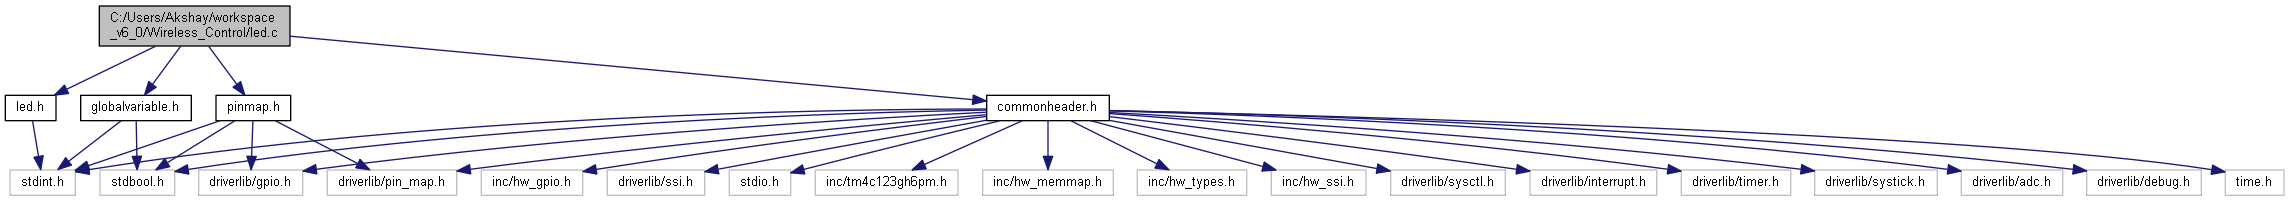
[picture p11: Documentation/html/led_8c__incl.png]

\end{center}
\end{figure}
\doxysubsection*{Functions}
\begin{DoxyCompactItemize}
\item 
\mbox{\Hypertarget{led_8c_a08d007fa711babfb56394eee2e6853dd}\label{led_8c_a08d007fa711babfb56394eee2e6853dd}} 
void \mbox{\hyperlink{led_8c_a08d007fa711babfb56394eee2e6853dd}{Timer2\+A\+P\+W\+M\+Init}} (void)
\begin{DoxyCompactList}\small\item\em Initializes Timer2A for P\+WM and configure port pin for the P\+WM o/p. \end{DoxyCompactList}\item 
\mbox{\Hypertarget{led_8c_af59abf4cefacd197620fdc094387a80d}\label{led_8c_af59abf4cefacd197620fdc094387a80d}} 
void \mbox{\hyperlink{led_8c_af59abf4cefacd197620fdc094387a80d}{Led\+\_\+\+Init}} ()
\begin{DoxyCompactList}\small\item\em Initializes o/p pin \& P\+WM for driving L\+ED. Check \mbox{\hyperlink{pinmap_8h}{pinmap.\+h}} for pin no. Uses Timer 2A. \end{DoxyCompactList}\item 
\mbox{\Hypertarget{led_8c_a95d5adeb4ba89d9b912dbab83af989cf}\label{led_8c_a95d5adeb4ba89d9b912dbab83af989cf}} 
void \mbox{\hyperlink{led_8c_a95d5adeb4ba89d9b912dbab83af989cf}{Led\+\_\+\+On}} ()
\begin{DoxyCompactList}\small\item\em Turn On L\+ED, Intensity depends on parameter passed via \mbox{\hyperlink{led_8h_af9a9d9bff04c1097512cd6a2502c8a54}{Led\+\_\+\+Intensity\+\_\+\+Update(int8\+\_\+t)}};. \end{DoxyCompactList}\item 
\mbox{\Hypertarget{led_8c_ad5564c27864e985679fd21e9dcc33f75}\label{led_8c_ad5564c27864e985679fd21e9dcc33f75}} 
void \mbox{\hyperlink{led_8c_ad5564c27864e985679fd21e9dcc33f75}{Led\+\_\+\+Off}} ()
\begin{DoxyCompactList}\small\item\em Turns Off L\+ED. \end{DoxyCompactList}\item 
\mbox{\Hypertarget{led_8c_a90c0e30307c996674bd6932d74b088b6}\label{led_8c_a90c0e30307c996674bd6932d74b088b6}} 
void \mbox{\hyperlink{led_8c_a90c0e30307c996674bd6932d74b088b6}{Led\+\_\+\+Intensity\+\_\+\+Update}} (int8\+\_\+t Led\+\_\+\+Intensity)
\begin{DoxyCompactList}\small\item\em Led Intensity\+: 0 to 5. Uses global variable for max value allowed. \end{DoxyCompactList}\end{DoxyCompactItemize}

\doxysubsection{Detailed Description}
Driver for L\+ED strip control. 

\begin{DoxyAuthor}{Author}
Akshay Pampatwar 
\end{DoxyAuthor}
\begin{DoxyVersion}{Version}
0.\+0 
\end{DoxyVersion}
\begin{DoxyDate}{Date}
Apr 17, 2020 
\end{DoxyDate}

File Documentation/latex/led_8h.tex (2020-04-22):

\hypertarget{led_8h}{}\doxysection{C\+:/\+Users/\+Akshay/workspace\+\_\+v6\+\_\+0/\+Wireless\+\_\+\+Control/led.h File Reference}
\label{led_8h}\index{C:/Users/Akshay/workspace\_v6\_0/Wireless\_Control/led.h@{C:/Users/Akshay/workspace\_v6\_0/Wireless\_Control/led.h}}

Function prototypes for L\+ED strip control.  

{\ttfamily \#include $<$stdint.\+h$>$}\newline
Include dependency graph for led.\+h\+:\nopagebreak
\begin{figure}[H]
\begin{center}
\leavevmode
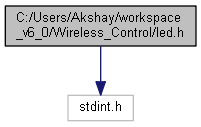
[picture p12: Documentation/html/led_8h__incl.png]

\end{center}
\end{figure}
This graph shows which files directly or indirectly include this file\+:\nopagebreak
\begin{figure}[H]
\begin{center}
\leavevmode
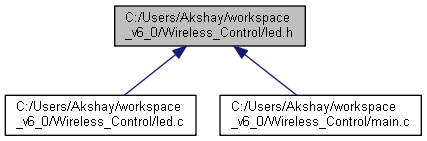
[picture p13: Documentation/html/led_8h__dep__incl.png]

\end{center}
\end{figure}
\doxysubsection*{Functions}
\begin{DoxyCompactItemize}
\item 
\mbox{\Hypertarget{led_8h_af1aee968a5ceeb7915921aa6d78aca23}\label{led_8h_af1aee968a5ceeb7915921aa6d78aca23}} 
void \mbox{\hyperlink{led_8h_af1aee968a5ceeb7915921aa6d78aca23}{Led\+\_\+\+Init}} (void)
\begin{DoxyCompactList}\small\item\em Initializes o/p pin \& P\+WM for driving L\+ED. Check \mbox{\hyperlink{pinmap_8h}{pinmap.\+h}} for pin no. Uses Timer 2A. \end{DoxyCompactList}\item 
\mbox{\Hypertarget{led_8h_a39675df62ae72fa5af35fc7ec2e8c950}\label{led_8h_a39675df62ae72fa5af35fc7ec2e8c950}} 
void \mbox{\hyperlink{led_8h_a39675df62ae72fa5af35fc7ec2e8c950}{Led\+\_\+\+On}} (void)
\begin{DoxyCompactList}\small\item\em Turn On L\+ED, Intensity depends on parameter passed via \mbox{\hyperlink{led_8h_af9a9d9bff04c1097512cd6a2502c8a54}{Led\+\_\+\+Intensity\+\_\+\+Update(int8\+\_\+t)}};. \end{DoxyCompactList}\item 
\mbox{\Hypertarget{led_8h_a274dbef77287444be852fe96969b3c55}\label{led_8h_a274dbef77287444be852fe96969b3c55}} 
void \mbox{\hyperlink{led_8h_a274dbef77287444be852fe96969b3c55}{Led\+\_\+\+Off}} (void)
\begin{DoxyCompactList}\small\item\em Turns Off L\+ED. \end{DoxyCompactList}\item 
\mbox{\Hypertarget{led_8h_af9a9d9bff04c1097512cd6a2502c8a54}\label{led_8h_af9a9d9bff04c1097512cd6a2502c8a54}} 
void \mbox{\hyperlink{led_8h_af9a9d9bff04c1097512cd6a2502c8a54}{Led\+\_\+\+Intensity\+\_\+\+Update}} (int8\+\_\+t)
\begin{DoxyCompactList}\small\item\em Led Intensity\+: 0 to 5. Uses global variable for max value allowed. \end{DoxyCompactList}\end{DoxyCompactItemize}

\doxysubsection{Detailed Description}
Function prototypes for L\+ED strip control. 

Middle layer. Initializes o/p port to command L\+ED driver. \begin{DoxyAuthor}{Author}
Akshay Pampatwar 
\end{DoxyAuthor}
\begin{DoxyVersion}{Version}
0.\+0 
\end{DoxyVersion}
\begin{DoxyDate}{Date}
Apr 17, 2020 
\end{DoxyDate}

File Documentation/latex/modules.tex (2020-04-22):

\doxysection{Modules}
Here is a list of all modules\+:\begin{DoxyCompactList}
\item \contentsline{section}{Wireless Appliances control}{\pageref{group___wi_control}}{}
\end{DoxyCompactList}

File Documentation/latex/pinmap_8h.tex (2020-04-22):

\hypertarget{pinmap_8h}{}\doxysection{C\+:/\+Users/\+Akshay/workspace\+\_\+v6\+\_\+0/\+Wireless\+\_\+\+Control/pinmap.h File Reference}
\label{pinmap_8h}\index{C:/Users/Akshay/workspace\_v6\_0/Wireless\_Control/pinmap.h@{C:/Users/Akshay/workspace\_v6\_0/Wireless\_Control/pinmap.h}}

Pin assignment of i/p \& o/p of appliances with uC.  

{\ttfamily \#include $<$stdint.\+h$>$}\newline
{\ttfamily \#include $<$stdbool.\+h$>$}\newline
{\ttfamily \#include \char`\"{}driverlib/gpio.\+h\char`\"{}}\newline
{\ttfamily \#include \char`\"{}driverlib/pin\+\_\+map.\+h\char`\"{}}\newline
Include dependency graph for pinmap.\+h\+:\nopagebreak
\begin{figure}[H]
\begin{center}
\leavevmode
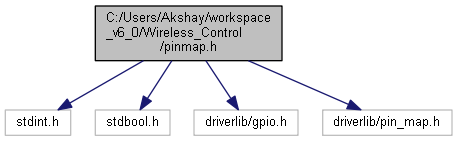
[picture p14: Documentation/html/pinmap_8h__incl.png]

\end{center}
\end{figure}
This graph shows which files directly or indirectly include this file\+:\nopagebreak
\begin{figure}[H]
\begin{center}
\leavevmode

\end{center}
\end{figure}
\doxysubsection*{Macros}
\begin{DoxyCompactItemize}
\item 
\mbox{\Hypertarget{pinmap_8h_afc65d1b0a36790c8ae7da5086d728527}\label{pinmap_8h_afc65d1b0a36790c8ae7da5086d728527}} 
\#define {\bfseries Plug1\+\_\+\+SW}~G\+P\+I\+O\+\_\+\+P\+I\+N\+\_\+0
\item 
\mbox{\Hypertarget{pinmap_8h_a3e56951e803b2091754b0cc18b9885a8}\label{pinmap_8h_a3e56951e803b2091754b0cc18b9885a8}} 
\#define {\bfseries Plug2\+\_\+\+SW}~G\+P\+I\+O\+\_\+\+P\+I\+N\+\_\+1
\item 
\mbox{\Hypertarget{pinmap_8h_a454ba58f31ecd6ad47389d354e130064}\label{pinmap_8h_a454ba58f31ecd6ad47389d354e130064}} 
\#define {\bfseries Led\+\_\+\+SW}~G\+P\+I\+O\+\_\+\+P\+I\+N\+\_\+2
\item 
\mbox{\Hypertarget{pinmap_8h_a71cc70193716ec33a70ab244665bee1f}\label{pinmap_8h_a71cc70193716ec33a70ab244665bee1f}} 
\#define {\bfseries Fan\+\_\+\+SW}~G\+P\+I\+O\+\_\+\+P\+I\+N\+\_\+3
\item 
\mbox{\Hypertarget{pinmap_8h_a2d70166aad758b72dcea20001c1a26e7}\label{pinmap_8h_a2d70166aad758b72dcea20001c1a26e7}} 
\#define {\bfseries Led\+\_\+\+Inc\+\_\+\+SW}~G\+P\+I\+O\+\_\+\+P\+I\+N\+\_\+4
\item 
\mbox{\Hypertarget{pinmap_8h_a2302ccf3a83f7dde981265daef4f13b1}\label{pinmap_8h_a2302ccf3a83f7dde981265daef4f13b1}} 
\#define {\bfseries Led\+\_\+\+Dec\+\_\+\+SW}~G\+P\+I\+O\+\_\+\+P\+I\+N\+\_\+5
\item 
\mbox{\Hypertarget{pinmap_8h_a935a3cc29014893956cd0865c8cd937a}\label{pinmap_8h_a935a3cc29014893956cd0865c8cd937a}} 
\#define {\bfseries Fan\+\_\+\+Inc\+\_\+\+SW}~G\+P\+I\+O\+\_\+\+P\+I\+N\+\_\+6
\item 
\mbox{\Hypertarget{pinmap_8h_a74a0c0af9db83c63feeb83835af6aba6}\label{pinmap_8h_a74a0c0af9db83c63feeb83835af6aba6}} 
\#define {\bfseries Fan\+\_\+\+Dec\+\_\+\+SW}~G\+P\+I\+O\+\_\+\+P\+I\+N\+\_\+7
\item 
\mbox{\Hypertarget{pinmap_8h_a57ce07898fd2d28e93ed59568ba682f9}\label{pinmap_8h_a57ce07898fd2d28e93ed59568ba682f9}} 
\#define {\bfseries Fan\+\_\+\+State}~G\+P\+I\+O\+\_\+\+P\+I\+N\+\_\+3
\item 
\mbox{\Hypertarget{pinmap_8h_add12e0168c8b9e91c84855c3869b0948}\label{pinmap_8h_add12e0168c8b9e91c84855c3869b0948}} 
\#define {\bfseries Led\+\_\+\+State}~G\+P\+I\+O\+\_\+\+P\+I\+N\+\_\+2
\item 
\mbox{\Hypertarget{pinmap_8h_a6a5cd8913182f7d82127c74deb13407d}\label{pinmap_8h_a6a5cd8913182f7d82127c74deb13407d}} 
\#define {\bfseries Fan\+\_\+1}~G\+P\+I\+O\+\_\+\+P\+I\+N\+\_\+2
\item 
\mbox{\Hypertarget{pinmap_8h_a4c6e71246541f67eef72bd519402ec46}\label{pinmap_8h_a4c6e71246541f67eef72bd519402ec46}} 
\#define {\bfseries Fan\+\_\+2}~G\+P\+I\+O\+\_\+\+P\+I\+N\+\_\+3
\item 
\mbox{\Hypertarget{pinmap_8h_a41c885b4baea527d888d66c6675d51d8}\label{pinmap_8h_a41c885b4baea527d888d66c6675d51d8}} 
\#define {\bfseries Fan\+\_\+3}~G\+P\+I\+O\+\_\+\+P\+I\+N\+\_\+0
\item 
\mbox{\Hypertarget{pinmap_8h_ab8e9b7a2ed1b2cccaf73d5f62936578e}\label{pinmap_8h_ab8e9b7a2ed1b2cccaf73d5f62936578e}} 
\#define {\bfseries Fan\+\_\+4}~G\+P\+I\+O\+\_\+\+P\+I\+N\+\_\+4
\item 
\mbox{\Hypertarget{pinmap_8h_a3c6072b9070f1fb0b794ac434ab092a8}\label{pinmap_8h_a3c6072b9070f1fb0b794ac434ab092a8}} 
\#define {\bfseries Fan\+\_\+5}~G\+P\+I\+O\+\_\+\+P\+I\+N\+\_\+0
\item 
\mbox{\Hypertarget{pinmap_8h_a832524b1941a55145906337cb19e4cb5}\label{pinmap_8h_a832524b1941a55145906337cb19e4cb5}} 
\#define {\bfseries Plug1\+\_\+\+State}~G\+P\+I\+O\+\_\+\+P\+I\+N\+\_\+2
\item 
\mbox{\Hypertarget{pinmap_8h_ab7d79da5c4739034f3e1813803f4355e}\label{pinmap_8h_ab7d79da5c4739034f3e1813803f4355e}} 
\#define {\bfseries Plug2\+\_\+\+State}~G\+P\+I\+O\+\_\+\+P\+I\+N\+\_\+3
\item 
\mbox{\Hypertarget{pinmap_8h_a5938ef724b5a81ffecf8f1499c1e8397}\label{pinmap_8h_a5938ef724b5a81ffecf8f1499c1e8397}} 
\#define {\bfseries Plug1\+\_\+\+Op}~G\+P\+I\+O\+\_\+\+P\+I\+N\+\_\+5
\item 
\mbox{\Hypertarget{pinmap_8h_a47c4193d49419fb36023036ed4d40c71}\label{pinmap_8h_a47c4193d49419fb36023036ed4d40c71}} 
\#define {\bfseries Plug2\+\_\+\+Op}~G\+P\+I\+O\+\_\+\+P\+I\+N\+\_\+6
\item 
\mbox{\Hypertarget{pinmap_8h_a8039d8bb76f824f5d0d16f0d80c5deba}\label{pinmap_8h_a8039d8bb76f824f5d0d16f0d80c5deba}} 
\#define {\bfseries Fan\+\_\+\+Scr\+\_\+\+Op}~G\+P\+I\+O\+\_\+\+P\+I\+N\+\_\+7
\item 
\mbox{\Hypertarget{pinmap_8h_a0e118bb281f2fa34a137cfb21bddf807}\label{pinmap_8h_a0e118bb281f2fa34a137cfb21bddf807}} 
\#define {\bfseries Led\+\_\+\+Op}~G\+P\+I\+O\+\_\+\+P\+F4\+\_\+\+T2\+C\+C\+P0
\item 
\mbox{\Hypertarget{pinmap_8h_a2e603822a0d3c45d48fded379ea01d2a}\label{pinmap_8h_a2e603822a0d3c45d48fded379ea01d2a}} 
\#define {\bfseries Led\+\_\+\+Op\+\_\+\+Pin}~G\+P\+I\+O\+\_\+\+P\+I\+N\+\_\+4
\item 
\mbox{\Hypertarget{pinmap_8h_a4128de22dc90ee4d9129bdcdec59ac32}\label{pinmap_8h_a4128de22dc90ee4d9129bdcdec59ac32}} 
\#define {\bfseries Z\+CD}~G\+P\+I\+O\+\_\+\+P\+I\+N\+\_\+5
\item 
\mbox{\Hypertarget{pinmap_8h_a977a75afcd68a84a4c27828336d5dbc5}\label{pinmap_8h_a977a75afcd68a84a4c27828336d5dbc5}} 
\#define {\bfseries A\+C\+\_\+\+IN}~G\+P\+I\+O\+\_\+\+P\+I\+N\+\_\+2
\item 
\mbox{\Hypertarget{pinmap_8h_a278e098e1898f109000c4bce78f3c416}\label{pinmap_8h_a278e098e1898f109000c4bce78f3c416}} 
\#define {\bfseries Bt\+\_\+\+En}~G\+P\+I\+O\+\_\+\+P\+I\+N\+\_\+5
\item 
\mbox{\Hypertarget{pinmap_8h_acff1b6b27bb18a5a6681117fce921506}\label{pinmap_8h_acff1b6b27bb18a5a6681117fce921506}} 
\#define {\bfseries Bt\+\_\+\+Tx}~G\+P\+I\+O\+\_\+\+P\+D7\+\_\+\+U2\+TX
\item 
\mbox{\Hypertarget{pinmap_8h_a09452d708e807888e4ff8906ee53edb9}\label{pinmap_8h_a09452d708e807888e4ff8906ee53edb9}} 
\#define {\bfseries Bt\+\_\+\+Rx}~G\+P\+I\+O\+\_\+\+P\+D6\+\_\+\+U2\+RX
\item 
\mbox{\Hypertarget{pinmap_8h_aed61975b933eb3fba752ae0dbfec924d}\label{pinmap_8h_aed61975b933eb3fba752ae0dbfec924d}} 
\#define {\bfseries Bt\+\_\+\+Tx\+\_\+\+Pin}~G\+P\+I\+O\+\_\+\+P\+I\+N\+\_\+7
\item 
\mbox{\Hypertarget{pinmap_8h_ad2ffd8015da8bd0647a4ac25d5ed63f3}\label{pinmap_8h_ad2ffd8015da8bd0647a4ac25d5ed63f3}} 
\#define {\bfseries Bt\+\_\+\+Rx\+\_\+\+Pin}~G\+P\+I\+O\+\_\+\+P\+I\+N\+\_\+6
\item 
\mbox{\Hypertarget{pinmap_8h_a32916a847090b087076a5bec92c78c33}\label{pinmap_8h_a32916a847090b087076a5bec92c78c33}} 
\#define {\bfseries G\+P\+I\+O\+\_\+1}~G\+P\+I\+O\+\_\+\+P\+I\+N\+\_\+0
\item 
\mbox{\Hypertarget{pinmap_8h_ae5b14b85fd16cf9cc9c37cecf533f83b}\label{pinmap_8h_ae5b14b85fd16cf9cc9c37cecf533f83b}} 
\#define {\bfseries G\+P\+I\+O\+\_\+2}~G\+P\+I\+O\+\_\+\+P\+I\+N\+\_\+1
\item 
\mbox{\Hypertarget{pinmap_8h_a90d2d5c526ce5c0a551f533eccbee71a}\label{pinmap_8h_a90d2d5c526ce5c0a551f533eccbee71a}} 
\#define {\bfseries A\+D\+C1}~G\+P\+I\+O\+\_\+\+P\+I\+N\+\_\+4
\item 
\mbox{\Hypertarget{pinmap_8h_a1803853d40a775230d2bd01a8a15ea91}\label{pinmap_8h_a1803853d40a775230d2bd01a8a15ea91}} 
\#define {\bfseries Rx}~G\+P\+I\+O\+\_\+\+P\+I\+N\+\_\+4
\item 
\mbox{\Hypertarget{pinmap_8h_abbb96fbbe5d24b8f12a1fae621ced4d3}\label{pinmap_8h_abbb96fbbe5d24b8f12a1fae621ced4d3}} 
\#define {\bfseries Tx}~G\+P\+I\+O\+\_\+\+P\+I\+N\+\_\+5
\item 
\mbox{\Hypertarget{pinmap_8h_a538e3ec60828cfabae7e3011d73d2093}\label{pinmap_8h_a538e3ec60828cfabae7e3011d73d2093}} 
\#define {\bfseries P\+WM}~G\+P\+I\+O\+\_\+\+P\+I\+N\+\_\+3
\item 
\mbox{\Hypertarget{pinmap_8h_a549c6fea143151843c75309dd1e8a0c8}\label{pinmap_8h_a549c6fea143151843c75309dd1e8a0c8}} 
\#define {\bfseries Port\+A\+\_\+\+Ip\+Mask}~( Led\+\_\+\+Inc\+\_\+\+SW $\vert$ Led\+\_\+\+Dec\+\_\+\+SW $\vert$ Fan\+\_\+\+Inc\+\_\+\+SW $\vert$ Fan\+\_\+\+Dec\+\_\+\+SW )
\item 
\mbox{\Hypertarget{pinmap_8h_a25fa364d63b3c1c6738e14eff6e427e6}\label{pinmap_8h_a25fa364d63b3c1c6738e14eff6e427e6}} 
\#define {\bfseries Port\+A\+\_\+\+Op\+Mask}~( Fan\+\_\+\+State $\vert$ Led\+\_\+\+State )
\item 
\mbox{\Hypertarget{pinmap_8h_aeb1855ded2da259d262c3ba6ba0014cf}\label{pinmap_8h_aeb1855ded2da259d262c3ba6ba0014cf}} 
\#define {\bfseries Port\+B\+\_\+\+Ip\+Mask}~( 0 )
\item 
\mbox{\Hypertarget{pinmap_8h_ab32dd7a51884ba21af9caa5ac5826023}\label{pinmap_8h_ab32dd7a51884ba21af9caa5ac5826023}} 
\#define {\bfseries Port\+B\+\_\+\+Op\+Mask}~( Fan\+\_\+1 $\vert$ Fan\+\_\+2 $\vert$ Bt\+\_\+\+En )
\item 
\mbox{\Hypertarget{pinmap_8h_ab19676f235654ab332017600cc6a3775}\label{pinmap_8h_ab19676f235654ab332017600cc6a3775}} 
\#define {\bfseries Port\+C\+\_\+\+Ip\+Mask}~( 0 )
\item 
\mbox{\Hypertarget{pinmap_8h_afb3a68ddabf48e6bc6f85a14b31325c5}\label{pinmap_8h_afb3a68ddabf48e6bc6f85a14b31325c5}} 
\#define {\bfseries Port\+C\+\_\+\+Op\+Mask}~( Fan\+\_\+4 $\vert$ Plug1\+\_\+\+Op $\vert$ Plug2\+\_\+\+Op $\vert$ Fan\+\_\+\+Scr\+\_\+\+Op)
\item 
\mbox{\Hypertarget{pinmap_8h_aaa6d797e7cbcb4965ad71cb91d838510}\label{pinmap_8h_aaa6d797e7cbcb4965ad71cb91d838510}} 
\#define {\bfseries Port\+D\+\_\+\+Ip\+Mask}~( Plug1\+\_\+\+SW $\vert$ Plug2\+\_\+\+SW $\vert$ Led\+\_\+\+SW $\vert$ Fan\+\_\+\+SW )
\item 
\mbox{\Hypertarget{pinmap_8h_aab631e3c1c2d8e93f42769bafe43b80e}\label{pinmap_8h_aab631e3c1c2d8e93f42769bafe43b80e}} 
\#define {\bfseries Port\+E\+\_\+\+Ip\+Mask}~( 0 )
\item 
\mbox{\Hypertarget{pinmap_8h_a32fbdf1228dc715809bc5a34348fdca4}\label{pinmap_8h_a32fbdf1228dc715809bc5a34348fdca4}} 
\#define {\bfseries Port\+E\+\_\+\+Op\+Mask}~( Fan\+\_\+3 )
\end{DoxyCompactItemize}

\doxysubsection{Detailed Description}
Pin assignment of i/p \& o/p of appliances with uC. 

H\+AL\+: Hardware abstraction layer. Maps pin of tm4c123gh6pm uC with corresponding functionality. \begin{DoxyNote}{Note}
U can only change P\+IN maping in the same port. i.\+e. If u want to change pin no. assignment in portA then updated pin should be assigned in a port A only. 
\end{DoxyNote}
\begin{DoxyAuthor}{Author}
\$\+Akshay Pampatwar \$ 
\end{DoxyAuthor}
\begin{DoxyVersion}{Version}
\$0.\+0 \$ 
\end{DoxyVersion}
\begin{DoxyDate}{Date}
\$10th April 2020 \$ 
\end{DoxyDate}

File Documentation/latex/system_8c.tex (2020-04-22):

\hypertarget{system_8c}{}\doxysection{C\+:/\+Users/\+Akshay/workspace\+\_\+v6\+\_\+0/\+Wireless\+\_\+\+Control/system.c File Reference}
\label{system_8c}\index{C:/Users/Akshay/workspace\_v6\_0/Wireless\_Control/system.c@{C:/Users/Akshay/workspace\_v6\_0/Wireless\_Control/system.c}}

Driver for peripherals of tm4c123gh6pm uC.  

{\ttfamily \#include \char`\"{}system.\+h\char`\"{}}\newline
{\ttfamily \#include \char`\"{}pinmap.\+h\char`\"{}}\newline
{\ttfamily \#include \char`\"{}commonheader.\+h\char`\"{}}\newline
{\ttfamily \#include \char`\"{}input.\+h\char`\"{}}\newline
{\ttfamily \#include \char`\"{}bluetooth.\+h\char`\"{}}\newline
{\ttfamily \#include \char`\"{}driverlib/uart.\+h\char`\"{}}\newline
{\ttfamily \#include \char`\"{}driverlib/eeprom.\+h\char`\"{}}\newline
Include dependency graph for system.\+c\+:\nopagebreak
\begin{figure}[H]
\begin{center}
\leavevmode
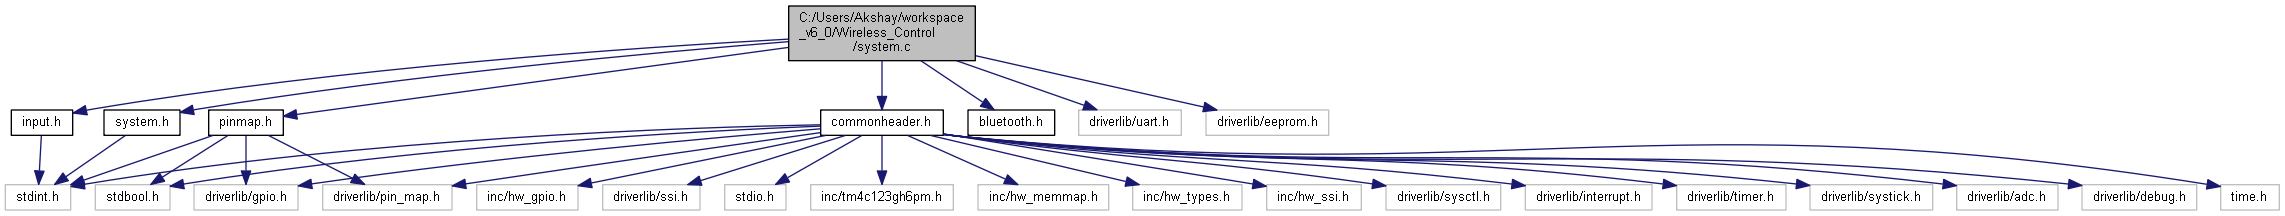
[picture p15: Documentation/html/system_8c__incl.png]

\end{center}
\end{figure}
\doxysubsection*{Functions}
\begin{DoxyCompactItemize}
\item 
void \mbox{\hyperlink{system_8c_a4de2e91e78a7dc2a2501959f85ca1bb2}{Timer0\+Init}} (uint32\+\_\+t debounce)
\item 
\mbox{\Hypertarget{system_8c_a74ceb5fbff5fd971c473d77538d3ea8c}\label{system_8c_a74ceb5fbff5fd971c473d77538d3ea8c}} 
void \mbox{\hyperlink{system_8c_a74ceb5fbff5fd971c473d77538d3ea8c}{Timer0\+Int\+Handler}} (void)
\begin{DoxyCompactList}\small\item\em I\+SR for Timer0 \+: Reads port A and D, packs it and passed on to \mbox{\hyperlink{input_8c_aa824b14a8fe97b88f0ba0ed98a3e1791}{Gpip()}} fn in \mbox{\hyperlink{input_8c}{input.\+c}}. \end{DoxyCompactList}\item 
\mbox{\Hypertarget{system_8c_adfdb874494a7e96ac1256869f1a7e9d4}\label{system_8c_adfdb874494a7e96ac1256869f1a7e9d4}} 
void \mbox{\hyperlink{system_8c_adfdb874494a7e96ac1256869f1a7e9d4}{Sys\+\_\+\+Init}} (void)
\begin{DoxyCompactList}\small\item\em Initializes system with 20M\+Hz C\+PU Clock and enable clk to all required ports. \end{DoxyCompactList}\item 
void \mbox{\hyperlink{system_8c_acf611d90e359ddd37bf100b55febf8bb}{Sys\+\_\+\+Gpip\+Init}} (uint32\+\_\+t debounce)
\item 
\mbox{\Hypertarget{system_8c_a858c121cead7d8b34a037695504b926e}\label{system_8c_a858c121cead7d8b34a037695504b926e}} 
void \mbox{\hyperlink{system_8c_a858c121cead7d8b34a037695504b926e}{Sys\+\_\+\+Eeprom\+\_\+\+Init}} ()
\begin{DoxyCompactList}\small\item\em Init eeprom. \end{DoxyCompactList}\item 
int8\+\_\+t \mbox{\hyperlink{system_8c_af287be012af33e6521b17064706323dc}{Sys\+\_\+\+Restore\+\_\+\+Byte}} (int8\+\_\+t address)
\item 
void \mbox{\hyperlink{system_8c_a95a32c6f93e18ebbb8ddd02e88014d01}{Sys\+\_\+\+Store\+\_\+\+Byte}} (int8\+\_\+t value, int8\+\_\+t address)
\end{DoxyCompactItemize}

\doxysubsection{Detailed Description}
Driver for peripherals of tm4c123gh6pm uC. 

\begin{DoxyAuthor}{Author}
Akshay Pampatwar 
\end{DoxyAuthor}
\begin{DoxyVersion}{Version}
0.\+0 
\end{DoxyVersion}
\begin{DoxyDate}{Date}
10th April 2020 
\end{DoxyDate}

\doxysubsection{Function Documentation}
\mbox{\Hypertarget{system_8c_acf611d90e359ddd37bf100b55febf8bb}\label{system_8c_acf611d90e359ddd37bf100b55febf8bb}} 
\index{system.c@{system.c}!Sys\_GpipInit@{Sys\_GpipInit}}
\index{Sys\_GpipInit@{Sys\_GpipInit}!system.c@{system.c}}
\doxysubsubsection{\texorpdfstring{Sys\_GpipInit()}{Sys\_GpipInit()}}
{\footnotesize\ttfamily void Sys\+\_\+\+Gpip\+Init (\begin{DoxyParamCaption}\item[{uint32\+\_\+t}]{debounce }\end{DoxyParamCaption})}

Initializes G\+P\+I\+Os as an input for switches and Timer 0 to take care of debounce. 
\begin{DoxyParams}{Parameters}
{\em debounce} & \+: Debounce Time setting for switches \\
\hline
\end{DoxyParams}

Definition at line 45 of file system.\+c.

Here is the caller graph for this function\+:\nopagebreak
\begin{figure}[H]
\begin{center}
\leavevmode

\end{center}
\end{figure}
\mbox{\Hypertarget{system_8c_af287be012af33e6521b17064706323dc}\label{system_8c_af287be012af33e6521b17064706323dc}} 
\index{system.c@{system.c}!Sys\_Restore\_Byte@{Sys\_Restore\_Byte}}
\index{Sys\_Restore\_Byte@{Sys\_Restore\_Byte}!system.c@{system.c}}
\doxysubsubsection{\texorpdfstring{Sys\_Restore\_Byte()}{Sys\_Restore\_Byte()}}
{\footnotesize\ttfamily int8\+\_\+t Sys\+\_\+\+Restore\+\_\+\+Byte (\begin{DoxyParamCaption}\item[{int8\+\_\+t}]{address }\end{DoxyParamCaption})}

Returns content from eeprom corresponding to address passed to it. 
\begin{DoxyParams}{Parameters}
{\em address} & 0 to n $\vert$ n belongs to Natural number \\
\hline
\end{DoxyParams}
\begin{DoxyReturn}{Returns}
Byte (int8\+\_\+t)\+: From addressed passed 
\end{DoxyReturn}

Definition at line 63 of file system.\+c.

\mbox{\Hypertarget{system_8c_a95a32c6f93e18ebbb8ddd02e88014d01}\label{system_8c_a95a32c6f93e18ebbb8ddd02e88014d01}} 
\index{system.c@{system.c}!Sys\_Store\_Byte@{Sys\_Store\_Byte}}
\index{Sys\_Store\_Byte@{Sys\_Store\_Byte}!system.c@{system.c}}
\doxysubsubsection{\texorpdfstring{Sys\_Store\_Byte()}{Sys\_Store\_Byte()}}
{\footnotesize\ttfamily void Sys\+\_\+\+Store\+\_\+\+Byte (\begin{DoxyParamCaption}\item[{int8\+\_\+t}]{value,  }\item[{int8\+\_\+t}]{address }\end{DoxyParamCaption})}

Store passed contents to an eeprom. 
\begin{DoxyParams}{Parameters}
{\em value} & 8 bit data which needs to be stored \\
\hline
{\em address} & 0 to n $\vert$ n belongs to Natural number \\
\hline
\end{DoxyParams}

Definition at line 70 of file system.\+c.

\mbox{\Hypertarget{system_8c_a4de2e91e78a7dc2a2501959f85ca1bb2}\label{system_8c_a4de2e91e78a7dc2a2501959f85ca1bb2}} 
\index{system.c@{system.c}!Timer0Init@{Timer0Init}}
\index{Timer0Init@{Timer0Init}!system.c@{system.c}}
\doxysubsubsection{\texorpdfstring{Timer0Init()}{Timer0Init()}}
{\footnotesize\ttfamily void Timer0\+Init (\begin{DoxyParamCaption}\item[{uint32\+\_\+t}]{debounce }\end{DoxyParamCaption})}

Init Timer0 for periodic triggering of a I\+SR for scanning i/p. 
\begin{DoxyParams}{Parameters}
{\em debounce} & \+: mS \\
\hline
\end{DoxyParams}

Definition at line 77 of file system.\+c.

Here is the call graph for this function\+:\nopagebreak
\begin{figure}[H]
\begin{center}
\leavevmode

\end{center}
\end{figure}

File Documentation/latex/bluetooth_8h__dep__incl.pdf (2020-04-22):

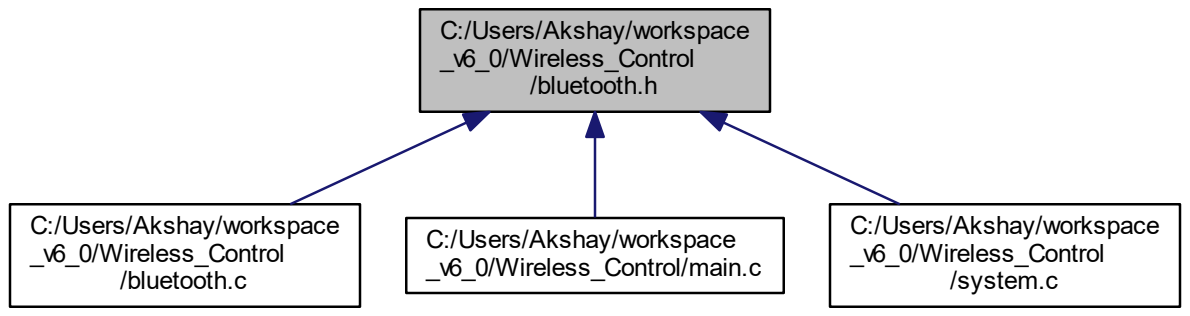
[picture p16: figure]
C:/Users/Akshay/workspace _v6_0/Wireless_Control /bluetooth.h; C:/Users/Akshay/workspace _v6_0/Wireless_Control /bluetooth.c; C:/Users/Akshay/workspace _v6_0/Wireless_Control/main.c; C:/Users/Akshay/workspace _v6_0/Wireless_Control /system.c

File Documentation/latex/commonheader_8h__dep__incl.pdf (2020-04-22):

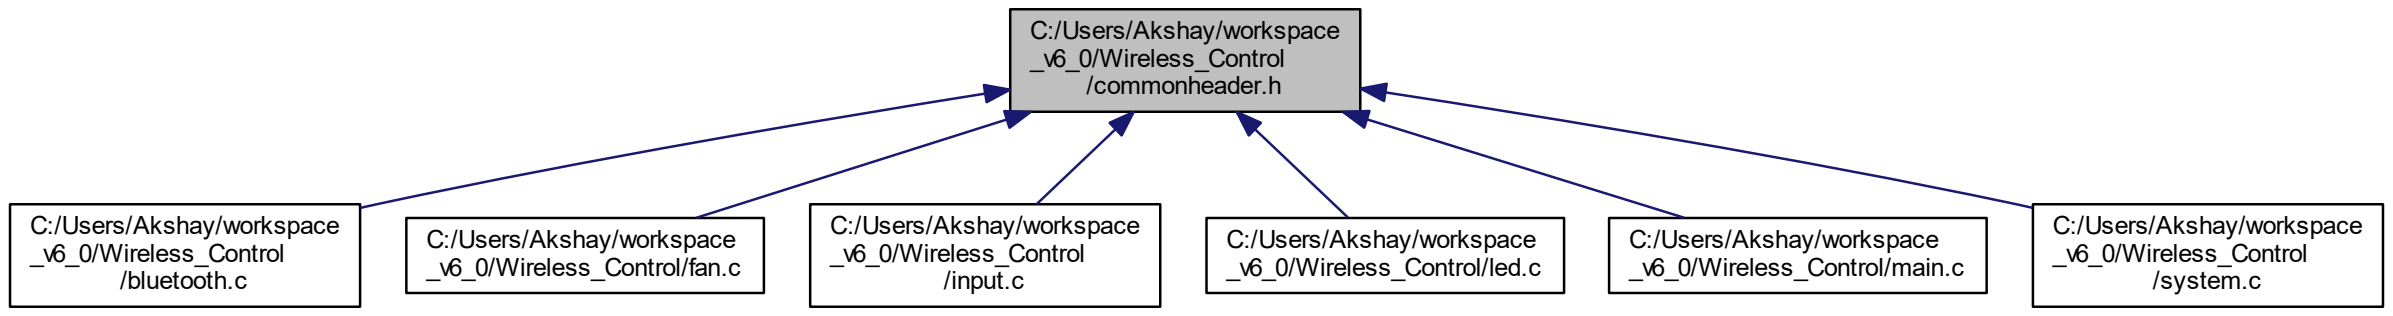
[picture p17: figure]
C:/Users/Akshay/workspace _v6_0/Wireless_Control /commonheader.h; C:/Users/Akshay/workspace _v6_0/Wireless_Control /bluetooth.c; C:/Users/Akshay/workspace _v6_0/Wireless_Control/fan.c; C:/Users/Akshay/workspace _v6_0/Wireless_Control /input.c; C:/Users/Akshay/workspace _v6_0/Wireless_Control/led.c; C:/Users/Akshay/workspace _v6_0/Wireless_Control/main.c; C:/Users/Akshay/workspace _v6_0/Wireless_Control /system.c

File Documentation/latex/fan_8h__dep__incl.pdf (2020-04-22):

C:/Users/Akshay/workspace
_v6_0/Wireless_Control/fan.h

C:/Users/Akshay/workspace
_v6_0/Wireless_Control/fan.c

C:/Users/Akshay/workspace
_v6_0/Wireless_Control/main.c

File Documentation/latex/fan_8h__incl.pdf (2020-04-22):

C:/Users/Akshay/workspace
_v6_0/Wireless_Control/fan.h

stdint.h

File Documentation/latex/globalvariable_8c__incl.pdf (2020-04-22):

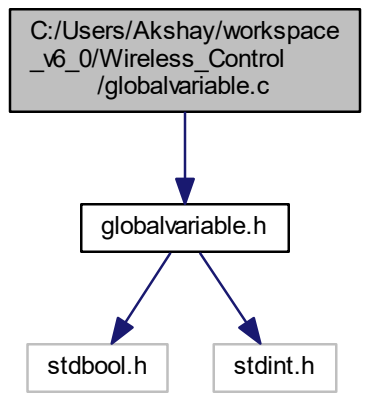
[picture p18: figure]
C:/Users/Akshay/workspace _v6_0/Wireless_Control /globalvariable.c; globalvariable.h; stdbool.h; stdint.h

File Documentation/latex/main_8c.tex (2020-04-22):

\hypertarget{main_8c}{}\doxysection{C\+:/\+Users/\+Akshay/workspace\+\_\+v6\+\_\+0/\+Wireless\+\_\+\+Control/main.c File Reference}
\label{main_8c}\index{C:/Users/Akshay/workspace\_v6\_0/Wireless\_Control/main.c@{C:/Users/Akshay/workspace\_v6\_0/Wireless\_Control/main.c}}

This is a main file.  

{\ttfamily \#include \char`\"{}system.\+h\char`\"{}}\newline
{\ttfamily \#include \char`\"{}input.\+h\char`\"{}}\newline
{\ttfamily \#include \char`\"{}bluetooth.\+h\char`\"{}}\newline
{\ttfamily \#include \char`\"{}plug.\+h\char`\"{}}\newline
{\ttfamily \#include \char`\"{}led.\+h\char`\"{}}\newline
{\ttfamily \#include \char`\"{}fan.\+h\char`\"{}}\newline
{\ttfamily \#include \char`\"{}commonheader.\+h\char`\"{}}\newline
{\ttfamily \#include \char`\"{}globalvariable.\+h\char`\"{}}\newline
Include dependency graph for main.\+c\+:\nopagebreak
\begin{figure}[H]
\begin{center}
\leavevmode
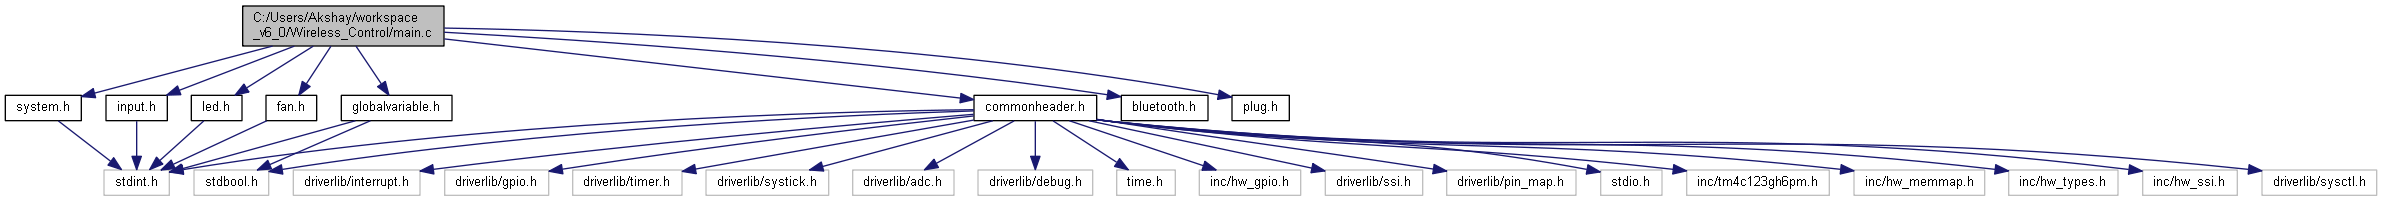
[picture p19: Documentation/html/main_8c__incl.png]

\end{center}
\end{figure}
\doxysubsection*{Functions}
\begin{DoxyCompactItemize}
\item 
\mbox{\Hypertarget{main_8c_aa25f2f7d400183f548ec805c54eaa9fc}\label{main_8c_aa25f2f7d400183f548ec805c54eaa9fc}} 
void \mbox{\hyperlink{main_8c_aa25f2f7d400183f548ec805c54eaa9fc}{control\+\_\+init}} (void)
\begin{DoxyCompactList}\small\item\em Initializes controller -\/ Application layer function. \end{DoxyCompactList}\item 
void \mbox{\hyperlink{main_8c_a92539439d06079cdfd5271a4648412f5}{controller}} (void)
\item 
\mbox{\Hypertarget{main_8c_a6288eba0f8e8ad3ab1544ad731eb7667}\label{main_8c_a6288eba0f8e8ad3ab1544ad731eb7667}} 
void {\bfseries main} (void)
\end{DoxyCompactItemize}

\doxysubsection{Detailed Description}
This is a main file. 

Consists of controller. Regularly scan for change in input using global variables. \begin{DoxyAuthor}{Author}
Akshay Pampatwar 
\end{DoxyAuthor}
\begin{DoxyVersion}{Version}
0.\+0 
\end{DoxyVersion}
\begin{DoxyDate}{Date}
9th April 2020 
\end{DoxyDate}

\doxysubsection{Function Documentation}
\mbox{\Hypertarget{main_8c_a92539439d06079cdfd5271a4648412f5}\label{main_8c_a92539439d06079cdfd5271a4648412f5}} 
\index{main.c@{main.c}!controller@{controller}}
\index{controller@{controller}!main.c@{main.c}}
\doxysubsubsection{\texorpdfstring{controller()}{controller()}}
{\footnotesize\ttfamily void controller (\begin{DoxyParamCaption}\item[{void}]{ }\end{DoxyParamCaption})}

Controller\+: Controls whole flow of operation

Sends updated command to appliances. Requires data from global variable.\+h 

Definition at line 66 of file main.\+c.

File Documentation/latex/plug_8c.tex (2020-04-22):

\hypertarget{plug_8c}{}\doxysection{C\+:/\+Users/\+Akshay/workspace\+\_\+v6\+\_\+0/\+Wireless\+\_\+\+Control/plug.c File Reference}
\label{plug_8c}\index{C:/Users/Akshay/workspace\_v6\_0/Wireless\_Control/plug.c@{C:/Users/Akshay/workspace\_v6\_0/Wireless\_Control/plug.c}}

Driver for controlling two plugs.  

{\ttfamily \#include \char`\"{}plug.\+h\char`\"{}}\newline
{\ttfamily \#include $<$stdint.\+h$>$}\newline
{\ttfamily \#include $<$stdbool.\+h$>$}\newline
{\ttfamily \#include \char`\"{}inc/tm4c123gh6pm.\+h\char`\"{}}\newline
{\ttfamily \#include \char`\"{}inc/hw\+\_\+ints.\+h\char`\"{}}\newline
{\ttfamily \#include \char`\"{}driverlib/gpio.\+h\char`\"{}}\newline
{\ttfamily \#include \char`\"{}driverlib/sysctl.\+h\char`\"{}}\newline
{\ttfamily \#include \char`\"{}inc/hw\+\_\+memmap.\+h\char`\"{}}\newline
{\ttfamily \#include \char`\"{}inc/hw\+\_\+types.\+h\char`\"{}}\newline
{\ttfamily \#include \char`\"{}pinmap.\+h\char`\"{}}\newline
Include dependency graph for plug.\+c\+:\nopagebreak
\begin{figure}[H]
\begin{center}
\leavevmode
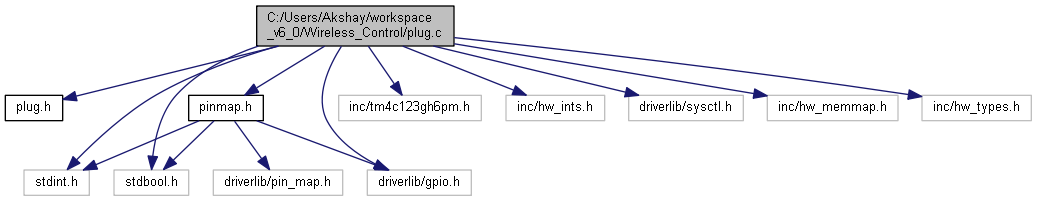
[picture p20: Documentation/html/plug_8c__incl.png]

\end{center}
\end{figure}
\doxysubsection*{Functions}
\begin{DoxyCompactItemize}
\item 
\mbox{\Hypertarget{plug_8c_afdd27cd5af8469d18d7ff3bad9c7cfb1}\label{plug_8c_afdd27cd5af8469d18d7ff3bad9c7cfb1}} 
void \mbox{\hyperlink{plug_8c_afdd27cd5af8469d18d7ff3bad9c7cfb1}{Plug\+\_\+\+Init}} ()
\begin{DoxyCompactList}\small\item\em Init corresponding gpio as an o/p. \end{DoxyCompactList}\item 
\mbox{\Hypertarget{plug_8c_abb48fafcbd945aeb6edb6cadec89dbb6}\label{plug_8c_abb48fafcbd945aeb6edb6cadec89dbb6}} 
void \mbox{\hyperlink{plug_8c_abb48fafcbd945aeb6edb6cadec89dbb6}{Plug1on}} ()
\begin{DoxyCompactList}\small\item\em Turns on plug 1 and its indicator. \end{DoxyCompactList}\item 
\mbox{\Hypertarget{plug_8c_a3e21f978d02df2c8c04df254ddd73445}\label{plug_8c_a3e21f978d02df2c8c04df254ddd73445}} 
void \mbox{\hyperlink{plug_8c_a3e21f978d02df2c8c04df254ddd73445}{Plug1off}} ()
\begin{DoxyCompactList}\small\item\em Turns off plug 1 and its indicator. \end{DoxyCompactList}\item 
\mbox{\Hypertarget{plug_8c_aa658a7714b9dfcdfc0ee6717a013dd7e}\label{plug_8c_aa658a7714b9dfcdfc0ee6717a013dd7e}} 
void \mbox{\hyperlink{plug_8c_aa658a7714b9dfcdfc0ee6717a013dd7e}{Plug2on}} ()
\begin{DoxyCompactList}\small\item\em Turns on plug 2 and its indicator. \end{DoxyCompactList}\item 
\mbox{\Hypertarget{plug_8c_ab17f082224d56f57b486cc6d24bb6fee}\label{plug_8c_ab17f082224d56f57b486cc6d24bb6fee}} 
void \mbox{\hyperlink{plug_8c_ab17f082224d56f57b486cc6d24bb6fee}{Plug2off}} ()
\begin{DoxyCompactList}\small\item\em Turns off plug 2 and its indicator. \end{DoxyCompactList}\end{DoxyCompactItemize}

\doxysubsection{Detailed Description}
Driver for controlling two plugs. 

\begin{DoxyAuthor}{Author}
Akshay Pampatwar 
\end{DoxyAuthor}
\begin{DoxyVersion}{Version}
0.\+0 
\end{DoxyVersion}
\begin{DoxyDate}{Date}
15th April 2020 
\end{DoxyDate}

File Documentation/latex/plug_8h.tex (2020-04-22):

\hypertarget{plug_8h}{}\doxysection{C\+:/\+Users/\+Akshay/workspace\+\_\+v6\+\_\+0/\+Wireless\+\_\+\+Control/plug.h File Reference}
\label{plug_8h}\index{C:/Users/Akshay/workspace\_v6\_0/Wireless\_Control/plug.h@{C:/Users/Akshay/workspace\_v6\_0/Wireless\_Control/plug.h}}

Function prototypes for controlling two plugs.  

This graph shows which files directly or indirectly include this file\+:\nopagebreak
\begin{figure}[H]
\begin{center}
\leavevmode
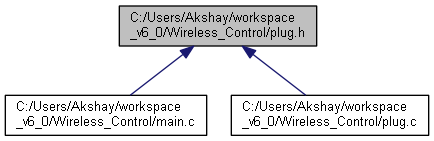
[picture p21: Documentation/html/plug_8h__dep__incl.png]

\end{center}
\end{figure}
\doxysubsection*{Functions}
\begin{DoxyCompactItemize}
\item 
\mbox{\Hypertarget{plug_8h_a279bdbe6eb2974fb0190884f6841379e}\label{plug_8h_a279bdbe6eb2974fb0190884f6841379e}} 
void \mbox{\hyperlink{plug_8h_a279bdbe6eb2974fb0190884f6841379e}{Plug\+\_\+\+Init}} (void)
\begin{DoxyCompactList}\small\item\em Init corresponding gpio as an o/p. \end{DoxyCompactList}\item 
\mbox{\Hypertarget{plug_8h_a8a13e35b90faf9f7f3161a7cbef12d40}\label{plug_8h_a8a13e35b90faf9f7f3161a7cbef12d40}} 
void \mbox{\hyperlink{plug_8h_a8a13e35b90faf9f7f3161a7cbef12d40}{Plug1on}} (void)
\begin{DoxyCompactList}\small\item\em Turns on plug 1 and its indicator. \end{DoxyCompactList}\item 
\mbox{\Hypertarget{plug_8h_a907d845f86ed4e7df9eaadfb4015949b}\label{plug_8h_a907d845f86ed4e7df9eaadfb4015949b}} 
void \mbox{\hyperlink{plug_8h_a907d845f86ed4e7df9eaadfb4015949b}{Plug1off}} (void)
\begin{DoxyCompactList}\small\item\em Turns off plug 1 and its indicator. \end{DoxyCompactList}\item 
\mbox{\Hypertarget{plug_8h_ac67c9f0e10f334270cac97b9f2a183b7}\label{plug_8h_ac67c9f0e10f334270cac97b9f2a183b7}} 
void \mbox{\hyperlink{plug_8h_ac67c9f0e10f334270cac97b9f2a183b7}{Plug2on}} (void)
\begin{DoxyCompactList}\small\item\em Turns on plug 2 and its indicator. \end{DoxyCompactList}\item 
\mbox{\Hypertarget{plug_8h_a50a341d87b628dd4b2b8d055e6a788f5}\label{plug_8h_a50a341d87b628dd4b2b8d055e6a788f5}} 
void \mbox{\hyperlink{plug_8h_a50a341d87b628dd4b2b8d055e6a788f5}{Plug2off}} (void)
\begin{DoxyCompactList}\small\item\em Turns off plug 2 and its indicator. \end{DoxyCompactList}\end{DoxyCompactItemize}

\doxysubsection{Detailed Description}
Function prototypes for controlling two plugs. 

\begin{DoxyVerb}Middle + HA layer.
\end{DoxyVerb}
 (i)Functions to initialize required port pin as o/p. (ii)Fns for controlling o/p of plug and indicator L\+E\+Ds \begin{DoxyAuthor}{Author}
Akshay Pampatwar 
\end{DoxyAuthor}
\begin{DoxyVersion}{Version}
0.\+0 
\end{DoxyVersion}
\begin{DoxyDate}{Date}
15th April 2020 
\end{DoxyDate}

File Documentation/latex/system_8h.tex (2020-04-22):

\hypertarget{system_8h}{}\doxysection{C\+:/\+Users/\+Akshay/workspace\+\_\+v6\+\_\+0/\+Wireless\+\_\+\+Control/system.h File Reference}
\label{system_8h}\index{C:/Users/Akshay/workspace\_v6\_0/Wireless\_Control/system.h@{C:/Users/Akshay/workspace\_v6\_0/Wireless\_Control/system.h}}

Fn prototypes for peripherals of tm4c123gh6pm uC.  

{\ttfamily \#include $<$stdint.\+h$>$}\newline
Include dependency graph for system.\+h\+:\nopagebreak
\begin{figure}[H]
\begin{center}
\leavevmode
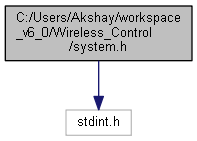
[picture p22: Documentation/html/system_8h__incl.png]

\end{center}
\end{figure}
This graph shows which files directly or indirectly include this file\+:\nopagebreak
\begin{figure}[H]
\begin{center}
\leavevmode
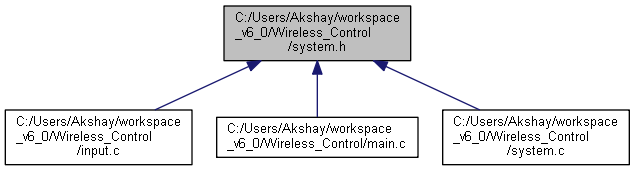
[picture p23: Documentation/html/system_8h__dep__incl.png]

\end{center}
\end{figure}
\doxysubsection*{Functions}
\begin{DoxyCompactItemize}
\item 
\mbox{\Hypertarget{system_8h_adfdb874494a7e96ac1256869f1a7e9d4}\label{system_8h_adfdb874494a7e96ac1256869f1a7e9d4}} 
void \mbox{\hyperlink{system_8h_adfdb874494a7e96ac1256869f1a7e9d4}{Sys\+\_\+\+Init}} (void)
\begin{DoxyCompactList}\small\item\em Initializes system with 20M\+Hz C\+PU Clock and enable clk to all required ports. \end{DoxyCompactList}\item 
void \mbox{\hyperlink{system_8h_acf611d90e359ddd37bf100b55febf8bb}{Sys\+\_\+\+Gpip\+Init}} (uint32\+\_\+t debounce)
\item 
\mbox{\Hypertarget{system_8h_a5b5e85126ae4035f07abce9b1351eb9f}\label{system_8h_a5b5e85126ae4035f07abce9b1351eb9f}} 
void \mbox{\hyperlink{system_8h_a5b5e85126ae4035f07abce9b1351eb9f}{Sys\+\_\+\+Eeprom\+\_\+\+Init}} (void)
\begin{DoxyCompactList}\small\item\em Init eeprom. \end{DoxyCompactList}\item 
int8\+\_\+t \mbox{\hyperlink{system_8h_af287be012af33e6521b17064706323dc}{Sys\+\_\+\+Restore\+\_\+\+Byte}} (int8\+\_\+t address)
\item 
void \mbox{\hyperlink{system_8h_a95a32c6f93e18ebbb8ddd02e88014d01}{Sys\+\_\+\+Store\+\_\+\+Byte}} (int8\+\_\+t value, int8\+\_\+t address)
\end{DoxyCompactItemize}

\doxysubsection{Detailed Description}
Fn prototypes for peripherals of tm4c123gh6pm uC. 

H\+AL\+: Hardware abstraction layer. Functions to initialize required peripherals of tm4c123gh6pm uC. \begin{DoxyAuthor}{Author}
Akshay Pampatwar 
\end{DoxyAuthor}
\begin{DoxyVersion}{Version}
0.\+0 
\end{DoxyVersion}
\begin{DoxyDate}{Date}
9th April 2020 
\end{DoxyDate}

\doxysubsection{Function Documentation}
\mbox{\Hypertarget{system_8h_acf611d90e359ddd37bf100b55febf8bb}\label{system_8h_acf611d90e359ddd37bf100b55febf8bb}} 
\index{system.h@{system.h}!Sys\_GpipInit@{Sys\_GpipInit}}
\index{Sys\_GpipInit@{Sys\_GpipInit}!system.h@{system.h}}
\doxysubsubsection{\texorpdfstring{Sys\_GpipInit()}{Sys\_GpipInit()}}
{\footnotesize\ttfamily void Sys\+\_\+\+Gpip\+Init (\begin{DoxyParamCaption}\item[{uint32\+\_\+t}]{debounce }\end{DoxyParamCaption})}

Initializes G\+P\+I\+Os as an input for switches and Timer 0 to take care of debounce. 
\begin{DoxyParams}{Parameters}
{\em debounce} & \+: Debounce Time setting for switches \\
\hline
\end{DoxyParams}

Definition at line 45 of file system.\+c.

Here is the caller graph for this function\+:\nopagebreak
\begin{figure}[H]
\begin{center}
\leavevmode

\end{center}
\end{figure}
\mbox{\Hypertarget{system_8h_af287be012af33e6521b17064706323dc}\label{system_8h_af287be012af33e6521b17064706323dc}} 
\index{system.h@{system.h}!Sys\_Restore\_Byte@{Sys\_Restore\_Byte}}
\index{Sys\_Restore\_Byte@{Sys\_Restore\_Byte}!system.h@{system.h}}
\doxysubsubsection{\texorpdfstring{Sys\_Restore\_Byte()}{Sys\_Restore\_Byte()}}
{\footnotesize\ttfamily int8\+\_\+t Sys\+\_\+\+Restore\+\_\+\+Byte (\begin{DoxyParamCaption}\item[{int8\+\_\+t}]{address }\end{DoxyParamCaption})}

Returns content from eeprom corresponding to address passed to it. 
\begin{DoxyParams}{Parameters}
{\em address} & 0 to n $\vert$ n belongs to Natural number \\
\hline
\end{DoxyParams}
\begin{DoxyReturn}{Returns}
Byte (int8\+\_\+t)\+: From addressed passed 
\end{DoxyReturn}

Definition at line 63 of file system.\+c.

\mbox{\Hypertarget{system_8h_a95a32c6f93e18ebbb8ddd02e88014d01}\label{system_8h_a95a32c6f93e18ebbb8ddd02e88014d01}} 
\index{system.h@{system.h}!Sys\_Store\_Byte@{Sys\_Store\_Byte}}
\index{Sys\_Store\_Byte@{Sys\_Store\_Byte}!system.h@{system.h}}
\doxysubsubsection{\texorpdfstring{Sys\_Store\_Byte()}{Sys\_Store\_Byte()}}
{\footnotesize\ttfamily void Sys\+\_\+\+Store\+\_\+\+Byte (\begin{DoxyParamCaption}\item[{int8\+\_\+t}]{value,  }\item[{int8\+\_\+t}]{address }\end{DoxyParamCaption})}

Store passed contents to an eeprom. 
\begin{DoxyParams}{Parameters}
{\em value} & 8 bit data which needs to be stored \\
\hline
{\em address} & 0 to n $\vert$ n belongs to Natural number \\
\hline
\end{DoxyParams}

Definition at line 70 of file system.\+c.

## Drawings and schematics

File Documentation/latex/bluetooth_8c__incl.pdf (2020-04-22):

C:/Users/Akshay/workspace
_v6_0/Wireless_Control

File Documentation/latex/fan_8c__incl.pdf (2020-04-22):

C:/Users/Akshay/workspace
_v6_0/Wireless_Control/fan.c

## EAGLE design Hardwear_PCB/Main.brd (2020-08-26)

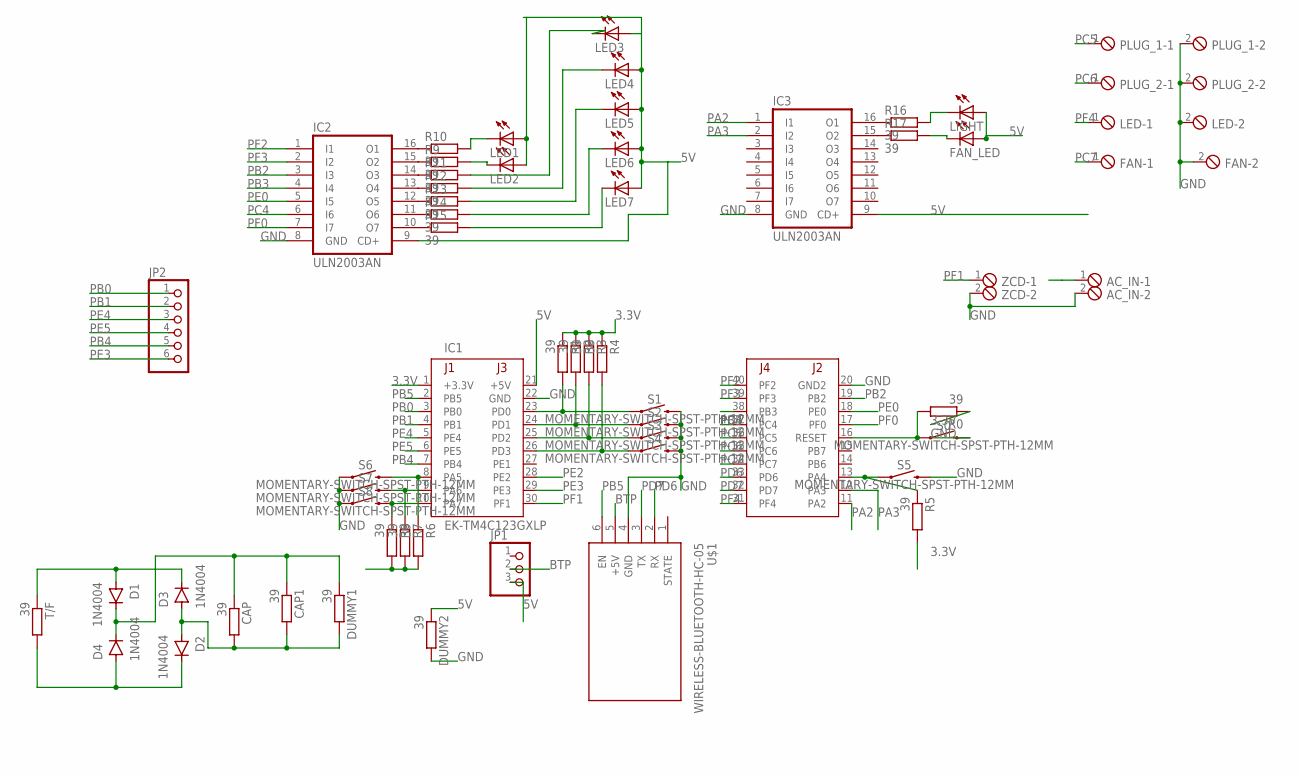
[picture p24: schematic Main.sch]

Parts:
AC_IN: MPT2; 2POL254
CAP, CAP1: 39; 0204/7
D1, D2, D3, D4: 1N4004; DO-41
DUMMY1, DUMMY2: 39; 0204/7
FAN: MPT2; 2POL254
FAN_LED: LED3MM
IC1: EK-TM4C123GXLP; TM4C123LAUNCHPAD
IC2, IC3: ULN2003AN; DIL16
JP1: PINHD-1X3CB; 1X03-CLEANBIG
JP2: PINHD-1X6; 1X06
LED: MPT2; 2POL254
LED1, LED2, LED3, LED4, LED5, LED6, LED7: LED3MM
LIGHT: LED3MM
PLUG_1, PLUG_2: MPT2; 2POL254
R0, R1, R2, R3, R4, R5, R6, R7, R8, R9, R10, R11, R12, R13, R14, R15, R16, R17: 39; 0204/7
S0, S1, S2, S3, S4, S5, S6, S7, S8: MOMENTARY-SWITCH-SPST-PTH-12MM; TACTILE_SWITCH_PTH_12MM
T/F: 39; 0204/7
U$1: WIRELESS-BLUETOOTH-HC-05
ZCD: MPT2; 2POL254

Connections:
3.3V: IC1.1 (+3.3V), R0.1, R1.1, R2.1, R3.1, R4.1, R5.2, R6.2, R7.2, R8.2
5V: DUMMY2.1, FAN_LED.A, IC1.21 (+5V), IC2.9 (CD+), IC3.9 (CD+), JP1.3, LED1.A, LED2.A, LED3.A, LED4.A, LED5.A, LED6.A, LED7.A, LIGHT.A
BTP: JP1.2, U$1.5 (+5V)
GND: AC_IN.2, DUMMY2.2, FAN.2, IC1.20 (GND2), IC1.22 (GND), IC2.8 (GND), IC3.8 (GND), LED.2, PLUG_1.2, PLUG_2.2, S0.3 (2), S1.3 (2), S2.3 (2), S3.3 (2), S4.3 (2), S5.3 (2), S6.1, S7.1, S8.1, U$1.4 (GND), ZCD.2
unnamed: IC1.23 (PD0), R1.2, S1.1
unnamed: IC1.24 (PD1), R2.2, S2.1
unnamed: IC1.25 (PD2), R3.2, S3.1
unnamed: IC1.26 (PD3), R4.2, S4.1
unnamed: IC1.13 (PA4), R5.1, S5.1
unnamed: IC1.8 (PA5), R6.1, S6.3 (2)
unnamed: IC1.16 (RESET), R0.2, S0.1
unnamed: IC1.9 (PA6), R7.1, S7.3 (2)
unnamed: IC1.10 (PA7), R8.1, S8.3 (2)
unnamed: IC2.15 (O2), R9.1
unnamed: IC2.16 (O1), R10.1
unnamed: IC2.14 (O3), R11.1
unnamed: IC2.13 (O4), R12.1
unnamed: D1.A, D3.C, T/F.1
unnamed: IC2.12 (O5), R13.1
unnamed: IC2.11 (O6), R14.1
unnamed: IC2.10 (O7), R15.1
unnamed: IC3.16 (O1), R16.1
unnamed: LED1.K (C), R10.2
unnamed: LED2.K (C), R9.2
unnamed: LED3.K (C), R11.2
unnamed: LED4.K (C), R12.2
unnamed: LED5.K (C), R13.2
unnamed: LED6.K (C), R14.2
unnamed: LED7.K (C), R15.2
unnamed: IC3.15 (O2), R17.1
unnamed: CAP.2, CAP1.2, D2.A, D3.A, DUMMY1.2
unnamed: CAP.1, CAP1.1, D1.C, D4.C, DUMMY1.1
unnamed: D2.C, D4.A, T/F.2
unnamed: LIGHT.K (C), R16.2
unnamed: FAN_LED.K (C), R17.2
PA2: IC1.11 (PA2), IC3.1 (I1)
PA3: IC1.12 (PA3), IC3.2 (I2)
PB0: IC1.3 (PB0), JP2.1
PB1: IC1.4 (PB1), JP2.2
PB2: IC1.19 (PB2), IC2.3 (I3)
PB3: IC1.38 (PB3), IC2.4 (I4)
PB4: IC1.7 (PB4), JP2.5
PB5: IC1.2 (PB5), U$1.6 (EN)
PC4: IC1.37 (PC4), IC2.6 (I6)
PC5: IC1.36 (PC5), PLUG_1.1
PC6: IC1.35 (PC6), PLUG_2.1
PC7: FAN.1, IC1.34 (PC7)
PD6: IC1.33 (PD6), U$1.2 (RX)
PD7: IC1.32 (PD7), U$1.3 (TX)
PE0: IC1.18 (PE0), IC2.5 (I5)
PE2: AC_IN.1, IC1.28 (PE2)
PE3: IC1.29 (PE3), JP2.6
PE4: IC1.5 (PE4), JP2.3
PE5: IC1.6 (PE5), JP2.4
PF0: IC1.17 (PF0), IC2.7 (I7)
PF1: IC1.30 (PF1), ZCD.1
PF2: IC1.40 (PF2), IC2.1 (I1)
PF3: IC1.39 (PF3), IC2.2 (I2)
PF4: IC1.31 (PF4), LED.1

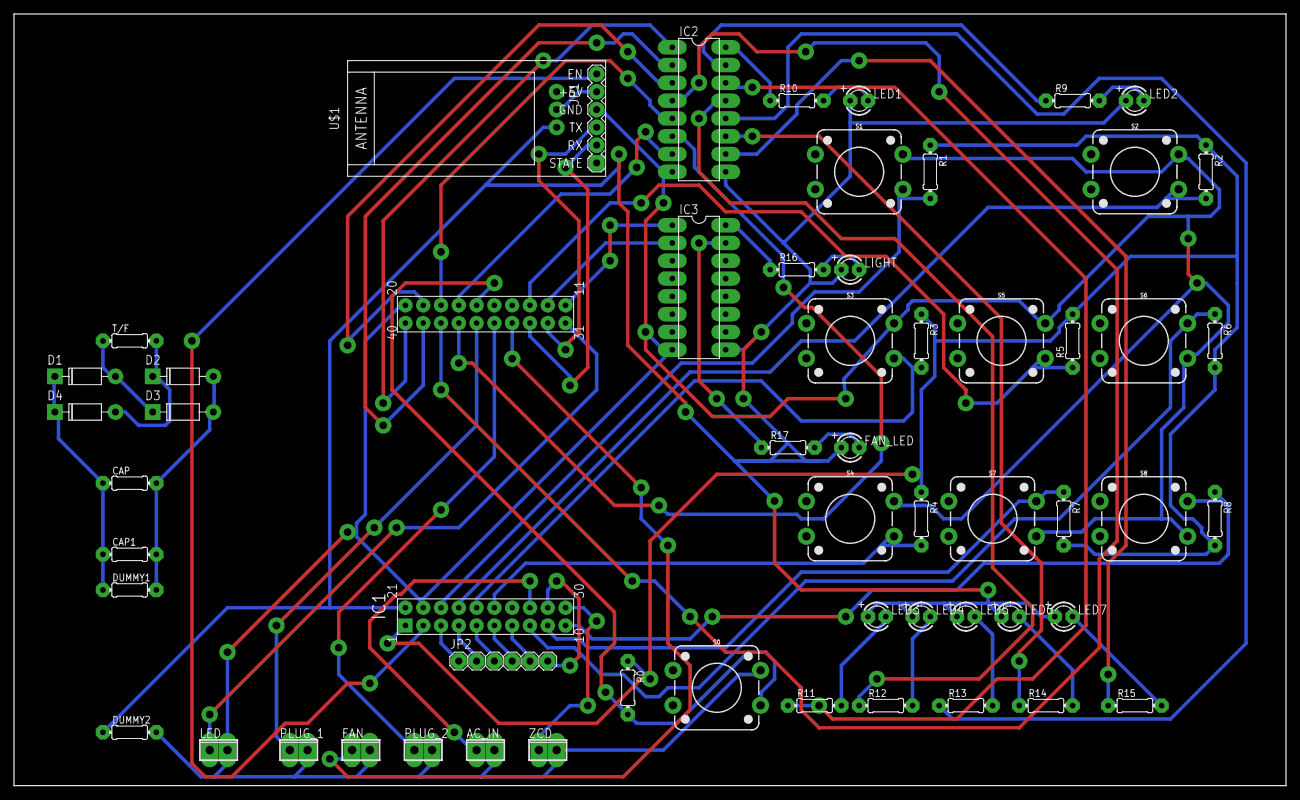
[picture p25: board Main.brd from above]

Board: 2 copper layers, 181.6 x 110.2 mm, 57 parts (0 on the bottom side), 59 nets.

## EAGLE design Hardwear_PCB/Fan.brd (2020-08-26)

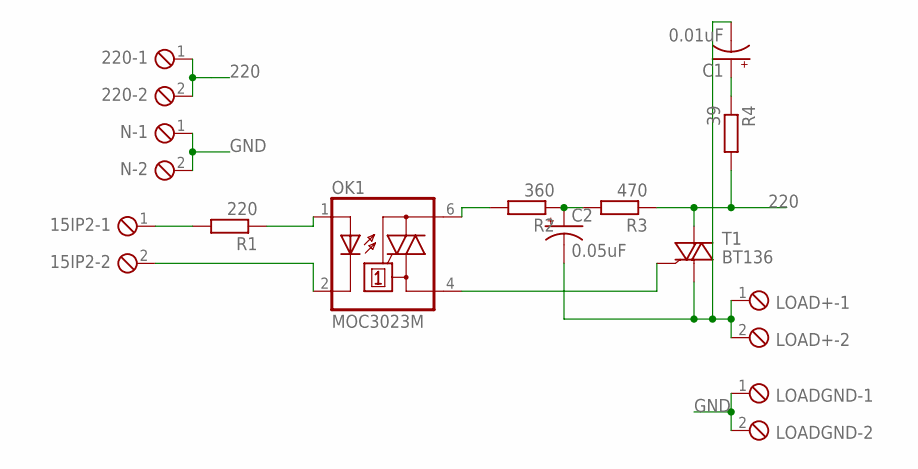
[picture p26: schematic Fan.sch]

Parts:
15IP2, 220: MPT2; 2POL254
C1: 0.01uF; CPOL-RADIAL-5MM-10MM
C2: 0.05uF; CPOL-RADIAL-5MM-10MM
LOAD+: MPT2; 2POL254
LOADGND: MPT2; 2POL254
N: MPT2; 2POL254
OK1: MOC3023M; DIL06
R1: 220; 0204/7
R2: 360; 0204/7
R3: 470; 0204/7
R4: 39; 0204/7
T1: BT136; TO220AB

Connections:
220: 220.1, 220.2, R3.1, R4.2, T1.2 (A2)
GND: LOADGND.1, LOADGND.2, N.1, N.2
unnamed: 15IP2.1, R1.2
unnamed: 15IP2.2, OK1.2 (C)
unnamed: OK1.1 (A), R1.1
unnamed: OK1.6 (A2), R2.2
unnamed: C2.+, R2.1, R3.2
unnamed: OK1.4 (A1), T1.3 (G)
unnamed: C1.+, R4.1
unnamed: C1.-, C2.-, LOAD+.1, LOAD+.2, T1.1 (A1)

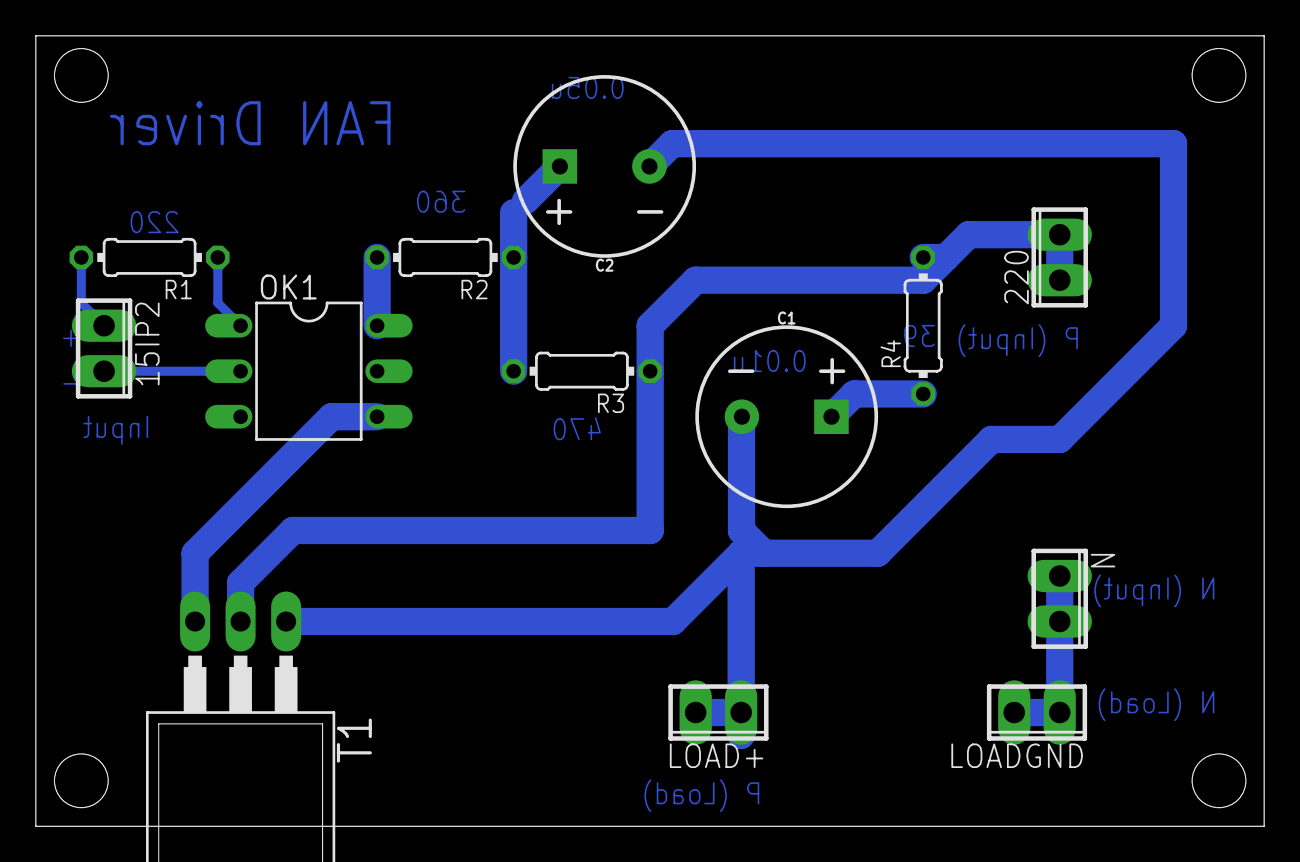
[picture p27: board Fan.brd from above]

Board: 2 copper layers, 68.6 x 44.1 mm, 13 parts (0 on the bottom side), 10 nets.

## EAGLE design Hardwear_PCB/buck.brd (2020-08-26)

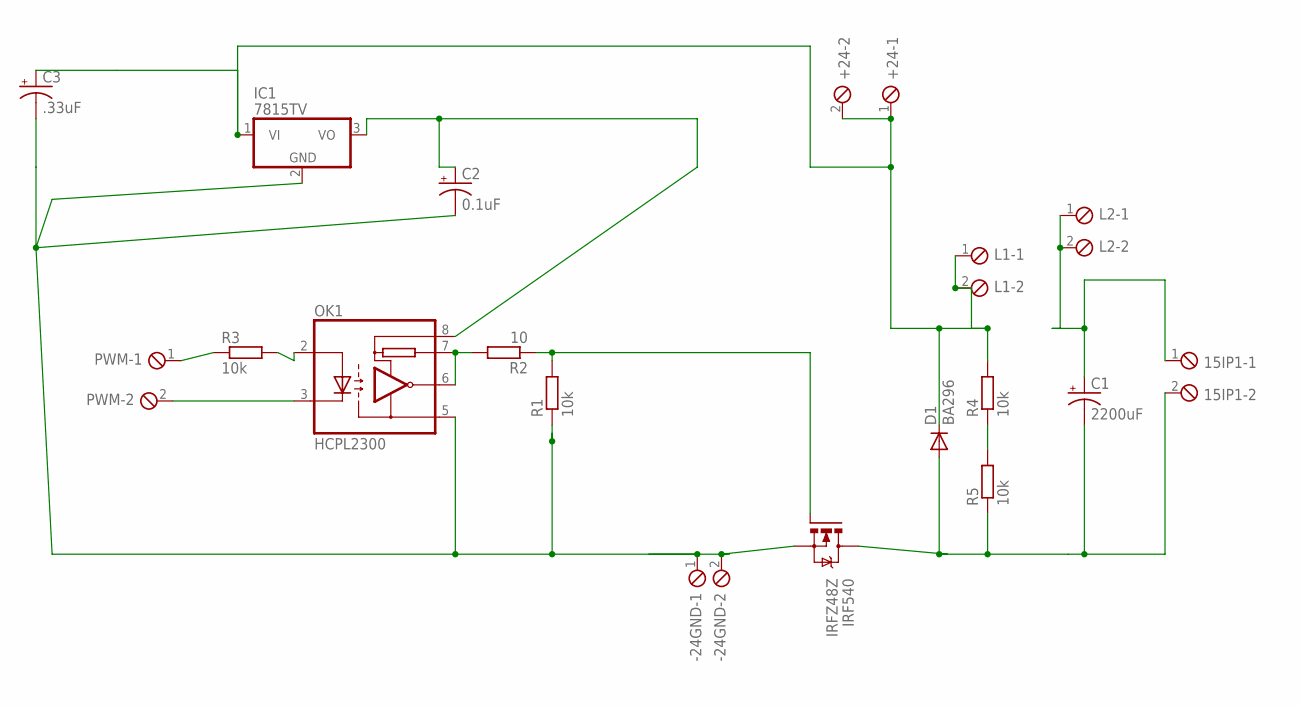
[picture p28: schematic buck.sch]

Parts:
15IP1: MPT2; 2POL254
+24: MPT2; 2POL254
-24GND: MPT2; 2POL254
C1: 2200uF; CPOL-RADIAL-5MM-10MM
C2: 0.1uF; CPOL-RADIAL-5MM-10MM
C3: .33uF; CPOL-RADIAL-5MM-10MM
D1: BA296; P2-15
IC1: 7815TV; TO220V
IRF540: IRFZ48Z; TO220BH
L1, L2: MPT2; 2POL254
OK1: HCPL2300; DIL08
PWM: MPT2; 2POL254
R1, R3, R4, R5: 10k; 0204/7
R2: 10; 0204/7

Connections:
GND: -24GND.1, -24GND.2, C2.-, C3.-, IC1.2 (GND), IRF540.S, OK1.5 (GND), R1.1
unnamed: PWM.1, R3.1
unnamed: R4.1, R5.2
unnamed: OK1.3 (C), PWM.2
unnamed: OK1.2 (A), R3.2
unnamed: +24.1, +24.2, C3.+, D1.C, IC1.1 (VI), L1.1, L1.2, R4.2
unnamed: 15IP1.2, C1.-, D1.A, IRF540.D, R5.1
unnamed: IRF540.G, R1.2, R2.1
unnamed: 15IP1.1, C1.+, L2.1, L2.2
unnamed: C2.+, IC1.3 (VO), OK1.8 (VCC)
unnamed: OK1.6 (VO), OK1.7 (RL), R2.2

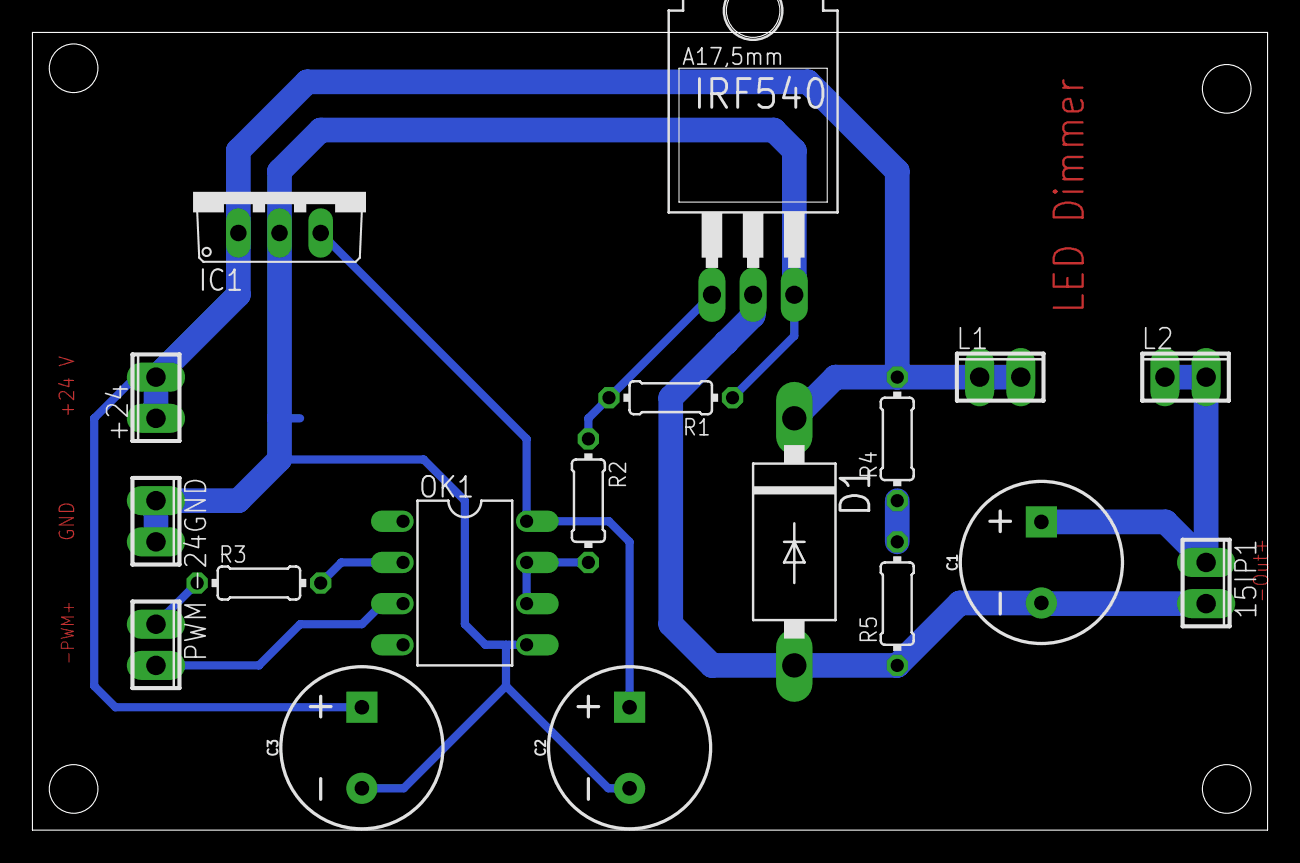
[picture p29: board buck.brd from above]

Board: 2 copper layers, 76.2 x 49.2 mm, 18 parts (0 on the bottom side), 11 nets.

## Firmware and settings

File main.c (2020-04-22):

/**
 * \file main.c
 * \ingroup WiControl
 * \brief This is a main file.
 *
 * Consists of controller. Regularly scan for change in input using global variables.
 * \author Akshay Pampatwar
 * \version 0.0
 * \date 9th April 2020
 */

/** \defgroup WiControl Wireless Appliances control
 *
 * \brief This project gives wireless control of home appliances to user.
 * 	Appliances can be turned on / off using app connected via bluetooth or electric switch board.
 */
#include "system.h"
#include "input.h"
#include "bluetooth.h"
#include "plug.h"
#include "led.h"
#include "fan.h"
#include "commonheader.h"
#include "globalvariable.h"



///Initializes controller - Application layer function
void control_init(void);

/**
 * Controller: Controls whole flow of operation
 *
 * Sends updated command to appliances. Requires data from global variable.h
 */
void controller(void);


void main(void)
{
	
		control_init();

		while(1)
		{
			controller();
		}
}

void control_init()
{
	Sys_Init();
	Plug_Init();
	Fan_Init();
	Led_Init();
	Input_Init();
	Wip_Init();

	Fan_Speed = Sys_Restore_Byte(0);
	Fan_Speed_Update(Fan_Speed);
	Led_Brightness = Sys_Restore_Byte(1);
	Led_Intensity_Update(Led_Brightness);
}


void controller()
{

		if(Fan_NCmd)
		{
			if(Fan_Cmd)
				Fan_On();
			else
				 Fan_Off();
			Fan_NCmd = 0;
		}
		 if(Fan_Nspeed)
		{
			Sys_Store_Byte(Fan_Speed, 0);
			Fan_Speed_Update(Fan_Speed);
			Fan_Nspeed = 0;
		}
		if(Led_NCmd)
		{
			if(Led_Cmd)
				Led_On();
			else
				Led_Off();

			Led_NCmd =0;
		}
		if(Led_NBrightness)
		{
			Sys_Store_Byte(Led_Brightness, 1);
			Led_Intensity_Update(Led_Brightness);
			Led_NBrightness=0;
		}
		if(Plug1_NCmd)
		{
			if(Plug1_Cmd)
				Plug1on();
			else
				Plug1off();
		}
		if(Plug2_NCmd)
		{
			if(Plug2_Cmd)
				Plug2on();
			else
				Plug2off();
		}
}

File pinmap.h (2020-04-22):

/**
 * \file pinmap.h
 * \ingroup WiControl
 * \brief Pin assignment of i/p & o/p of appliances with uC.
 *
 * HAL: Hardware abstraction layer.
 * Maps pin of tm4c123gh6pm uC with corresponding functionality.
 * @note U can only change PIN maping in the same port.
 * 		i.e. If u want to change pin no. assignment in portA then updated pin should be assigned in a port A only.
 * \author $Akshay Pampatwar $
 * \version $0.0 $
 * \date $10th April 2020 $
 */

#ifndef PINMAP_H_
#define PINMAP_H_

#include <stdint.h>
#include <stdbool.h>
#include "driverlib/gpio.h"
#include "driverlib/pin_map.h"

//Switch Input:

	//Port D:
	#define Plug1_SW GPIO_PIN_0
	#define Plug2_SW GPIO_PIN_1
	#define Led_SW GPIO_PIN_2
	#define Fan_SW GPIO_PIN_3

	//Port A:
	#define Led_Inc_SW GPIO_PIN_4
	#define Led_Dec_SW GPIO_PIN_5
	#define Fan_Inc_SW GPIO_PIN_6
	#define Fan_Dec_SW GPIO_PIN_7

//LED Indicator O/P:

	//Port A:
	#define Fan_State GPIO_PIN_3
	#define Led_State GPIO_PIN_2
	//Port B:
	#define Fan_1 GPIO_PIN_2
	#define Fan_2 GPIO_PIN_3
	//Port E:
	#define Fan_3 GPIO_PIN_0
	//Port C:
	#define Fan_4 GPIO_PIN_4
	//Port F:
	#define Fan_5 GPIO_PIN_0
	#define Plug1_State GPIO_PIN_2
	#define Plug2_State GPIO_PIN_3

//Control O/P:

	//Port C:
	#define Plug1_Op GPIO_PIN_5
	#define Plug2_Op GPIO_PIN_6
	#define Fan_Scr_Op GPIO_PIN_7
	//Port F:
	#define Led_Op GPIO_PF4_T2CCP0
	#define Led_Op_Pin GPIO_PIN_4

//Sensor I/P:

	//Port F:
	#define ZCD GPIO_PIN_5
	//Port E:
		//If changing this pin then need to make changes in fan.c
	#define AC_IN GPIO_PIN_2
//	#define AC_IN_Pin GPIO_PIN_2

//Bluetooth:

	//Port B:
	#define Bt_En GPIO_PIN_5
	//Port D:
	#define Bt_Tx GPIO_PD7_U2TX
	#define Bt_Rx GPIO_PD6_U2RX

	#define Bt_Tx_Pin GPIO_PIN_7
	#define Bt_Rx_Pin GPIO_PIN_6

//Extra Header:

	//Port B:
	#define GPIO_1 GPIO_PIN_0
	#define GPIO_2 GPIO_PIN_1
	#define ADC1 GPIO_PIN_4
	//Port E:
	#define Rx GPIO_PIN_4
	#define Tx GPIO_PIN_5
	#define PWM GPIO_PIN_3

//Port A:
	//Input Mask
	#define PortA_IpMask ( Led_Inc_SW | Led_Dec_SW | Fan_Inc_SW | Fan_Dec_SW )
	//Output Mask
	#define PortA_OpMask ( Fan_State | Led_State )

//Port B:
	//Input Mask
	#define PortB_IpMask ( 0 )
	//Output Mask
	#define PortB_OpMask ( Fan_1 | Fan_2 | Bt_En )

//Port C:
	//Input Mask
	#define PortC_IpMask ( 0 )
	//Output Mask
	#define PortC_OpMask ( Fan_4 | Plug1_Op | Plug2_Op | Fan_Scr_Op)

//Port D:
	//Input Mask
	#define PortD_IpMask ( Plug1_SW | Plug2_SW | Led_SW | Fan_SW )

//Port E:
	//Input Mask
	#define PortE_IpMask ( 0 ) 	//AC_IN )
	//Output Mask
	#define PortE_OpMask ( Fan_3 )

//Port E:

#endif /* PINMAP_H_ */

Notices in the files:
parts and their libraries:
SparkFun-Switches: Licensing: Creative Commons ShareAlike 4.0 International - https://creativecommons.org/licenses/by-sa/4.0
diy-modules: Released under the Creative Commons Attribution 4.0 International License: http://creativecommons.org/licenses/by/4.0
